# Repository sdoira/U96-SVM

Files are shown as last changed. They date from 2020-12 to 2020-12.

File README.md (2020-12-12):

# U96-SVM
Stereo vision front-end for Ultra96v2

## About
U96-SVM is an add-on board for Avnet Ultra96v2.
This board has dual CMOS image sensors and two mikroBUS sites.
This repository contains all design files for the hardware and a sample project 
which transfers stereo images through a USB interface.

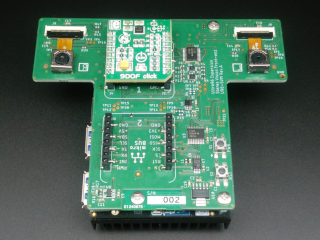
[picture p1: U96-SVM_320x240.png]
U96-SVM


## Tools

These tools are used to create this project.
1. Avnet Ultra96v2
2. Autodesk EAGLE 9.6.2
3. Xilinx Vivado 2020.1
4. Xilinx Vitis 2020.1

## PCB
This PCB is designed to be compliant with 96Boards specifications.
The number of layers is 4.
The minimum trace width and minimum drill diameter are 0.15mm and 0.25mm respectively.
This design rule is according to EuroCircuits 6D class.

EAGLE 9.6.2 is used in designing PCB.
This project doesn't contain Gerber files. EAGLE board layout file (.brd) is directly used to order manufacturing.
If you want to place an order simply upload the BRD file to the EuroCircuits website.
The assembly service is also possible by enabling the "Include assembly" option then upload the BOM file.

## USB Interface
This device is recognized as USB Video Class (UVC) device when connected to the host PC.
The sample project supports the following resolution both for USB2.0 and USB3.0.

| USB Ver. | Single Image Resolution | FPS  |
| :--- | :--- | :--- |
| 2.0 | 640 x 480 | 30 |
| 3.0 | 640 x 480 | 30 |

The left and right images are combined horizontally.
The actual output image is twice wide.

## Vivado Project
This repository contains 2 Vivado projects.
One of them is the Vivado top level project.
The other is a project for a user-created IP module.
Both of them can be created by running TCL scripts.
Refer to "create_project_dvp.pdf" and "create_project1.pdf" about how to create these projects.

## Vitis Project
The Vitis project contains a sample application named "usb_grabber".
This application, when launched, automatically starts DMA transferring of stereo images while waiting for a USB connection.
Refer to "create_vitis_project.pdf" about how to create the Vitis project.

## License
### Hardware
The hardware documentation and products included in this repository are licensed under the TAPR Open Hardware License (www.tapr.org/OHL).
The hardware documentation is contained in the following directory.

	/eagle/

### Software
The software design files included in this repository are available under the MIT license.
Such design files are contained in the following directories.

	/src/dvp/rtl/		--- Verilog-HDL RTL source
	/src/dvp/sim/		--- Verilog-HDL simulation test bench
	/src/usb_grabber/	--- C source

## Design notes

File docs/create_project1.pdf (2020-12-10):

Create project “project_1” | Dec.10.2020
1. Preface
This document describes a procedure to create “project_1” project. There are two methods to create this project. One of them is to use a script to automatically create the project. Such a script is included in the repository. The other is to create a project from scratch. This method is presented here in case the above script somehow won’t work. 2. Create “project_1” from script

Launch Vivado, type the following commands in “Tcl Console”. cd [Project Directory]/U96-SVM/vivado

source create_project_1.tcl
* board files for ultra96v2 must be installed. 3. Create “project_1” from scratch
3.1. Create a new project
If not, create the following working directory. [Project Directory]/U96-SVM/vivado

Launch Vivado, create a new project with the following properties. [Project Name]

Project name: project_1
Project location: [Project Directory]/U96-SVM/vivado
Create project subdirectory: Checked
[Project Type]
RTL Project: Selected
Do not specify sources at this time: Checked [Default Part]
Boards: Ultra96v2 Single Board Computer * board files for ultra96v2 must be installed. 3.2. Adding a block design

Click “Create Block Design” in the Flow Navigator to open “Create Block Design” dialog. Proceed with the following settings. Design name: design_1

Directory: [Project Directory]/U96-SVM/src
Specify source set: Design Sources

Click “+” icon in “BLOCK DESIGN->Diagram” to add an IP. Select “Zynq UltraScale+ MPSoC”. Click “Run Block Automation” and click “OK” with the default options.

Make the following connections. Source | Destination
pl_clk0 | maxihpm0_fpd_aclk
pl_clk0 | maxihpm1_fpd_aclk

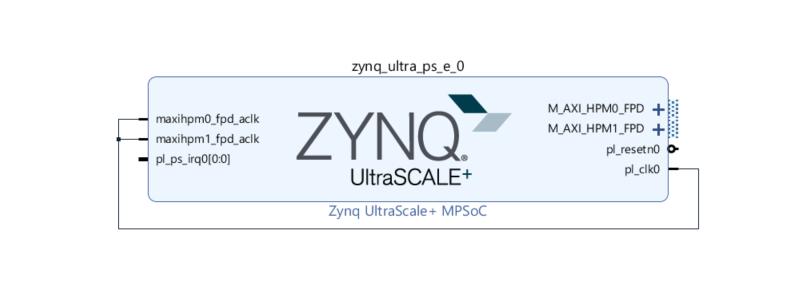
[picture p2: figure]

3.3. Adding IPs
Click “Tools->Settings...” to open “Settings” dialog. Select “Project Settings->IP->Repository”. Add the following path to “IP Repositories”. [Projecct Directory]/U96-SVM/src/ip_repo

*IP sources for “dvp” module must be exported under “ip_repo/dvp” directory.

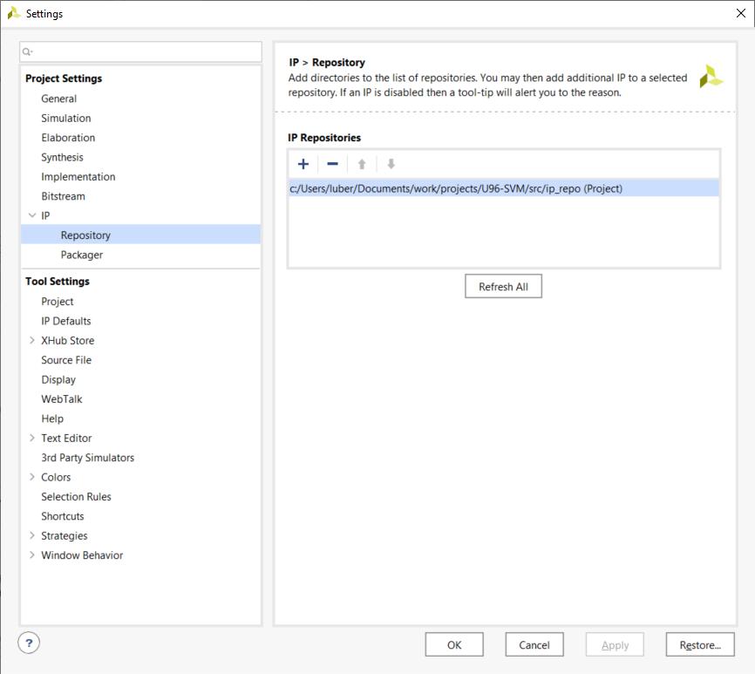
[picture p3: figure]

Double click “zynq_ultra_ps_e_0” in the BLOCK DESIGN. Select “PS-PL Configuration->PS-PL Interfaces->Slave Interfaces->AXI HP” Check “AXI HP0 FPD”. Add the following IPs by clicking “+” icon in “BLOCK DESIGN->Diagram” IP Name: “dvp_v1_0”. IP Name: MIPI CSI-2 Rx Subsystem

Component Name: mipi_csi2_rx_subsyst_0
Configuration-> Sybsystem Options-> Pixel Format: YUV422 8bit Serial Data Lanes: 2
DPHY Options->D-PHY Register Interface: Checked Shared Logic->Shared Logic->Include Shared Logic in core: Selected Pin Assigment-> Clock Lane->Pin Loc: N2
Data Lane0->Pin Loc: N5

Data Lane1->Pin Loc: M2

- IP Name: MIPI CSI-2 Rx Subsystem
Component Name: mipi_csi2_rx_subsyst_1
Configuration-> Sybsystem Options-> Pixel Format: YUV422 8bit
Serial Data Lanes: 2
DPHY Options->D-PHY Register Interface: Checked Shared Logic->Shared Logic->Include Shared Logic in example design: Selected Pin Assigment-> Clock Lane->Pin Loc: T3
Data Lane0->Pin Loc: P3
Data Lane1->Pin Loc: U2
- IP Name: Clocking Wizard
Component Name: clk_wiz_0
Output Clocks->clk_out1->Output Freq->Requested: 200
- IP Name: Clocking Wizard
Component Name: clk_wiz_1
Output Clocks->clk_out1->Output Freq->Requested: 24
Set the following port to “external” by right click the port then select “Make External”. Module | Signal
dvp_0 | gpio_in[1:0]
dvp_0 | led[1:0]
mipi_csi2_rx_subsyst_0 | mipi_phy_if
mipi_csi2_rx_subsyst_1 | mipi_phy_if
clk_wiz_1 | clk_out1
Connect the following signals. Source | Destination
Module | Signal | Module | Signal
dvp_0 | vrst1_n | mipi_csi2_rx_subsyst_0 | video_aresetn
dvp_0 | vrst2_n | mipi_csi2_rx_subsyst_1 | video_aresetn
dvp_0 | intr | zynq_ultra_ps_e_0 | pl_ps_irq0[0:0]
mipi_csi2_rx_subsyst_0 | video_out | dvp_0 | v1
mipi_csi2_rx_subsyst_1 | video_out | dvp_0 | v2
mipi_csi2_rx_subsyst_0 | clkoutphy_out | mipi_csi2_rx_subsyst_1 | clkoutphy_in
mipi_csi2_rx_subsyst_0 | pll_lock_out | mipi_csi2_rx_subsyst_1 | pll_lock_in
clk_wiz_0 | clk_out1 | mipi_csi2_rx_subsyst_0 | dphy_clk_200M
clk_wiz_0 | clk_out1 | mipi_csi2_rx_subsyst_1 | dphy_clk_200M

Click “Run Connection Automation” twice with the default parameters. Delete “reset_rtl” and “reset_rtl_0” input pins and connect to the following ports

instead. Source | Destination
Module | Signal | Module | Signal
clk_wiz_0 | reset | rst_ps8_0_100M | mb_reset
clk_wiz_1 | reset | rst_ps8_0_100M | mb_reset

Right click somewhere on the “Diagram” the click “Regenerate Layout”. “design_1” block design should look like this.

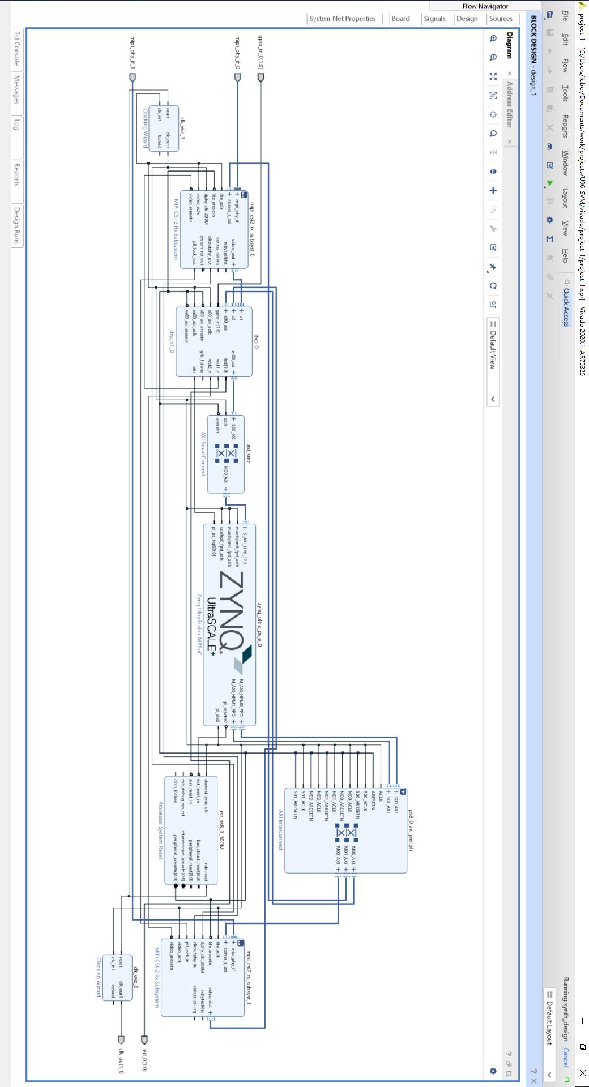
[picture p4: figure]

3.4. Create wrapper HDL
Right click “BLOCK DESIGN->Sources->Design Sources->design_1”. Click “Create HDL Wrapper...” in the menu to open “Create HDL Wrapper” dialog. Select “Let Vivado manage wrapper and auto-update” and click “OK”. 3.5. Pin assignment
Click “Run Synthesis” in the Flow Navigator. “Synthesis Completed” dialog will appear. Select “Open Synthesized Design” and click “OK”. Select “Window->I/O Ports”. “I/O Ports” tab will appear in the SYNTHESIZED DESIGN. Set the following pin location and I/O standard for each signal. Name | Package Pin | I/O Std
clk_out1_0 | E8 | LVCMOS18
gpio_in_0[1] | C5 | LVCMOS18
gpio_in_0[0] | G6 | LVCMOS18
led_0[1] | B9 | LVCMOS18
led_0[0] | A9 | LVCMOS18

Click “File->Constraints->Save As...” to open “Save Constraints” dialog. Proceed with the following settings. Create a new file: Selected

File type: XDC
File name: constr_1
File location: [Project Directory]/U96-SVM/src
3.7. Create a script
This process will make a script to automatically create this project. Click “Window->Tcl Console”. In the command line in the Tcl Console, type the following command. cd [Project Directory]/U96-SVM/vivado

write_project_tcl create_project_1.tcl

“create_project_1.tcl” will be created in the specified directory. 4. Export Hardware

Click “Generate Bitstream” in the Flow Navigator. Click “File->Export->Export Hardware” to open “Export Hardware Platform” dialog. Proceed with the following settings. [Export Hardware Platform]

Platform type: Fixed
[Output]
Include bitstream: Selected
[Files]
XSA file name: design_1_wrapper
Export to: [Project Directory]/U96-SVM/vivado

“design_1_wrapper.xsa” will be created in the specified directory.

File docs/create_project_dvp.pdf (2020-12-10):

Create project “dvp” | Dec.10.2020
1. Preface
This document describes a procedure to create “dvp” project. There are two methods to create this project. One of them is to use a script to automatically create the project. Such a script is included in the repository. The other is to create a project from scratch. This method is presented here in case the above script somehow won’t work. 2. Create “dvp” project from script

Launch Vivado, type the following commands in “Tcl Console”. cd [Project Directory]/U96-SVM/vivado

source create_project_dvp.tcl
* board files for ultra96v2 must be installed. 3. Create “dvp” project from scratch
3.1. Create a new project
Create the following working directory. [Project Directory]/U96-SVM/vivado

Launch Vivado, create a new project with the following properties. [Project Name]

Project name: dvp
Project location: [Project Directory]/U96-SVM/vivado
Create project subdirectory: Checked
[Project Type]
RTL Project: Selected
Do not specify sources at this time: Checked
[Default Part]
Boards->Display Name: Ultra96v2 Single Board Computer * board files for ultra96v2 must be installed. 3.2. Adding RTL sources

Click “Add Sources” in the Flow Navigator to open “Add Sources” dialog. Proceed with the following settings. [Add Sources]

Add or create design sources: Selected
[Add or Create Design Sources]
Click “Add Directories” to add the following directory. [Project Directory]/U96-SVM/src/dvp/rtl

Scan and add RTL include files into project: Checked Copy sources into project: Not checked

Add sources from subdirectories: Checked

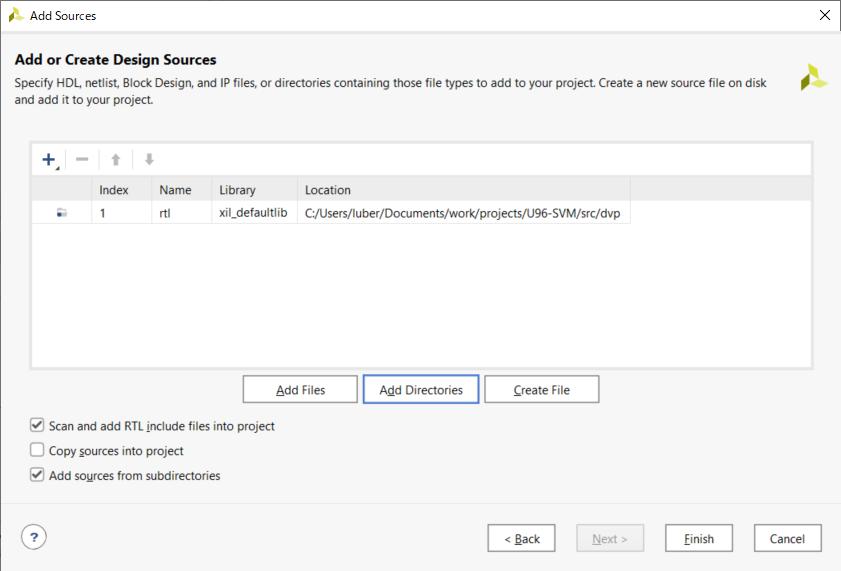
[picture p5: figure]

3.3. Adding Simulation sources
Click “Add Sources” in the Flow Navigator to open “Add Sources” dialog. Proceed with the following settings. [Add Sources]

Add or create simulation sources: Selected
[Add or Create Design Sources]
Click “Add Directories” to add the following directory. [Project Directory]/U96-SVM/src/dvp/sim

Scan and add RTL include files into project: Checked Copy sources into project: Not checked
Add sources from subdirectories: Checked
Include all design sources for simulation: Checked

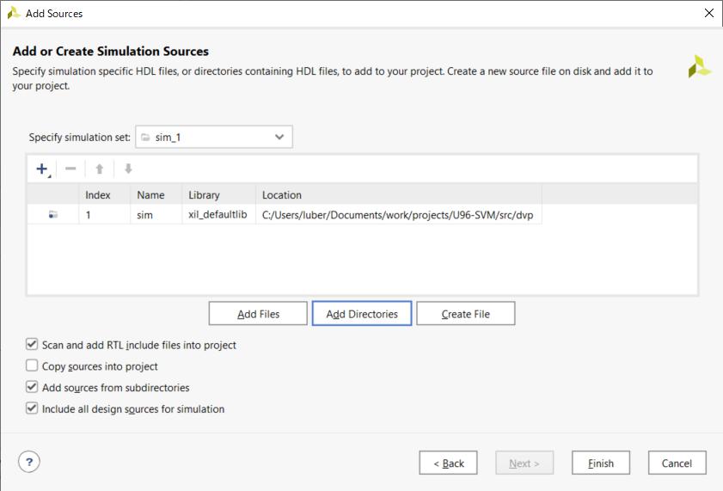
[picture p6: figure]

3.4. “arb_fifo” Click “IP Catalog” in the Flow Navigator. Select “FIFO Generator” and create an IP with the following settings. Component Name: arb_fifo

[Basic]
Fifo Implementation: Common Clock Block RAM
[Native Ports]
Data Port Parameters
Write Width: 36
Write Depth: 512
ECC, Output Register and Power Gating Options
Output Registers: Not checked
*Only the settings different from default are shown. “Generate Output Products” dialog will open. Click “Skip” for now. This is to reduce the number files that are put into git-controlled

directory in the later step.

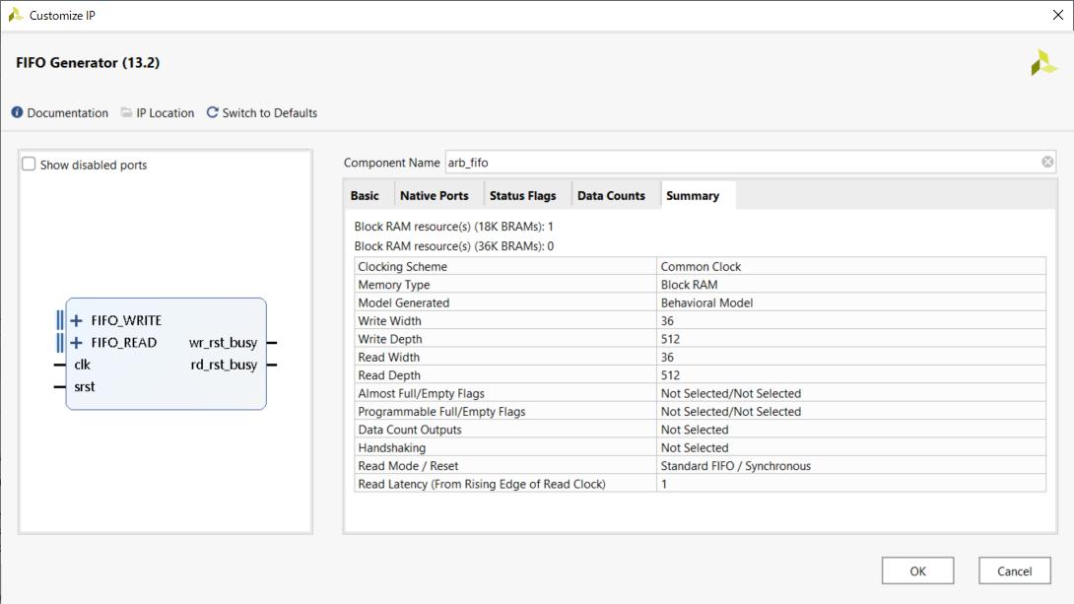
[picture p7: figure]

3.5. “grb_fifo” Click “IP Catalog” in the Flow Navigator. Select “FIFO Generator” and create an IP with the following settings. Component Name: grb_fifo

[Basic]
Fifo Implementation: Common Clock Block RAM
[Native Ports]
Data Port Parameters
Write Width: 32
Write Depth: 2048
ECC, Output Register and Power Gating Options Output Registers: Not checked
[Data Counts]
Data Count: Checked
*Only the settings different from default are shown. “Generate Output Products” dialog will open. Click “Skip” for now. This is to reduce the number files that are put into git-controlled

directory in the later step.

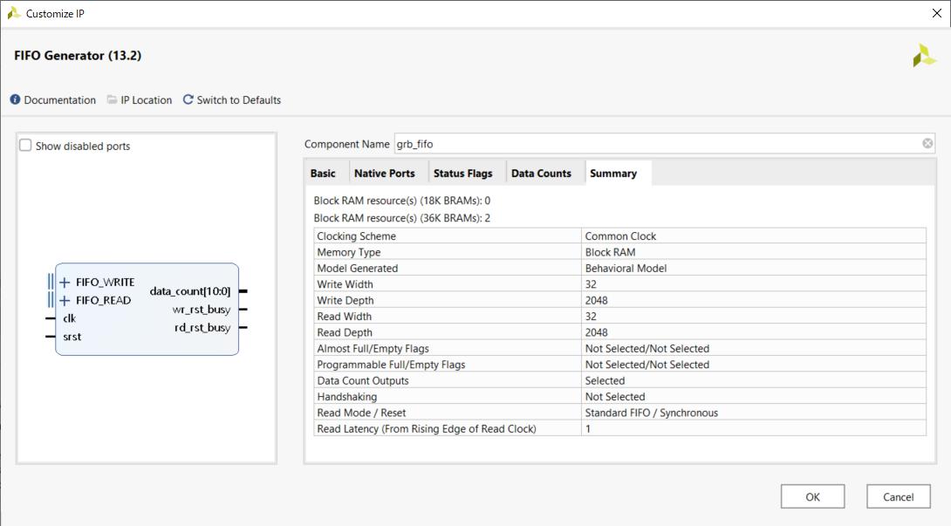
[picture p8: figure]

3.6. Moving IP sources
This process will move IP sources to git-controlled directory. Copy “arb_fifo directory as follows. Move from:

[Project Directory]/U96-SVM/vivado/dvp/dvp.srcs/sources_1/ip/arb_fifo Move to:
[Project Directory]/U96-SVM/src/dvp/ip/arb_fifo

Right click “arb_fifo” in “Sources” pane in PROJECT MANAGER. Select “Remove File from Project...”. Check “Also delete the projet local file/directory from disk”. Click OK. Click “Add Sources” in the Flow Navigator to open “Add Sources” dialog. Proceed with the following settings. [Add Sources]

Add or create design sources: Selected
[Add or Create Design Sources]
Clock “Add Files” to add the following file. [Project Directorh]/U96-SVM/src/dvp/ip/arb_fifo/arb_fifo.xci

Scan and add RTL include files into project: Checked
Copy sources into project: Not checked

Do the same operation with “grb_fifo”.

3.7. Create a script
This process will make a script that automatically creates this project. Click “Window->Tcl Console”. In the command line in the Tcl Console, type the following commands. cd [Project Directory]/U96-SVM/vivado

write_project_tcl create_project_dvp.tcl

“create_project_dvp.tcl” will be created in the specified directory. 4. Export IP

Click “Run Synthesis” in the Flow Navigator to see there aren’t any errors. Click “Tools->Create and Package New IP...” to open “Create and Package New IP” dialog. Proceed with the following settings. [Create Peripheral, Package IP or Package a Block Design]

Packaging Options
Package your current project: Selected
[Package Your Current Project]
IP location: [Project Directory]/U96-SVM/src/ip_repo/dvp

When prompted, choose to overwrite the existing files. Click “Finish”. “Package IP - dvp” will appear. Select “Review and Package”, click “Package IP”. IP sources for “dvp” are exported under “ip_repo/dvp” directory.

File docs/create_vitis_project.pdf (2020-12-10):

### Create Vitis project

Dec.10.2020
1. Preface
This document describes a procedure to create a Vitis project and a sample application named “usb_grabber”. 2. Create an application

If not, create the following Vitis working directory. [Project Directory]/U96-SVM/vitis

Launch Vitis, set the above directory as Vitis Workspace and click “Launch”. Click “Create Application Project” to open “New Application Project” dialog. Proceed with the following settings. [Platform]

Create a new platform from hardware (XSA)
Click “Browse...”
[Project Directory]/U96-SVM/vivado/design_1_wrapper.xsa [Application Project Details]
Application project name: usb_grabber
[Templates]
SW development templates: Empty Application
In “Application Project Settings”, click “Navigate to BSP Settings”. Click “Modify BSP Settings...” in “Board Support Package”. “Board Support Package Settings” dialog will open. Click “Overview->standalone” and make the following modification. Name | Value
stdin | psu_uart_1
stdout | psu_uart_1
This change is necessary because uart_1 is used as stdin/out in Ultra96v2 board.

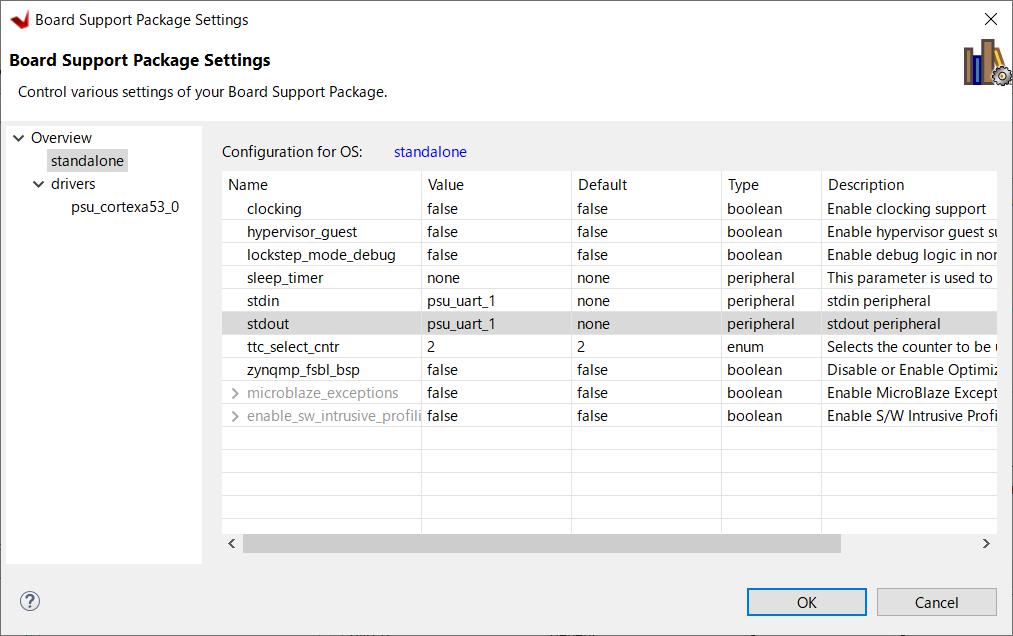
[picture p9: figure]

3. Import sources
Right click “usb_grabber_system->usb_grabber->src” in the “Explorer” and click “Import Sources...” from the menu to open “Import Sources” dialog. Proceed with the following settings. From directory: [Project Directory]/U96-SVM/src/usb_grabber

Click “Select All”. Click “Advanced”. Create links in workspace: Checked. (This will create symbolic links under the project directory without actual copying.)

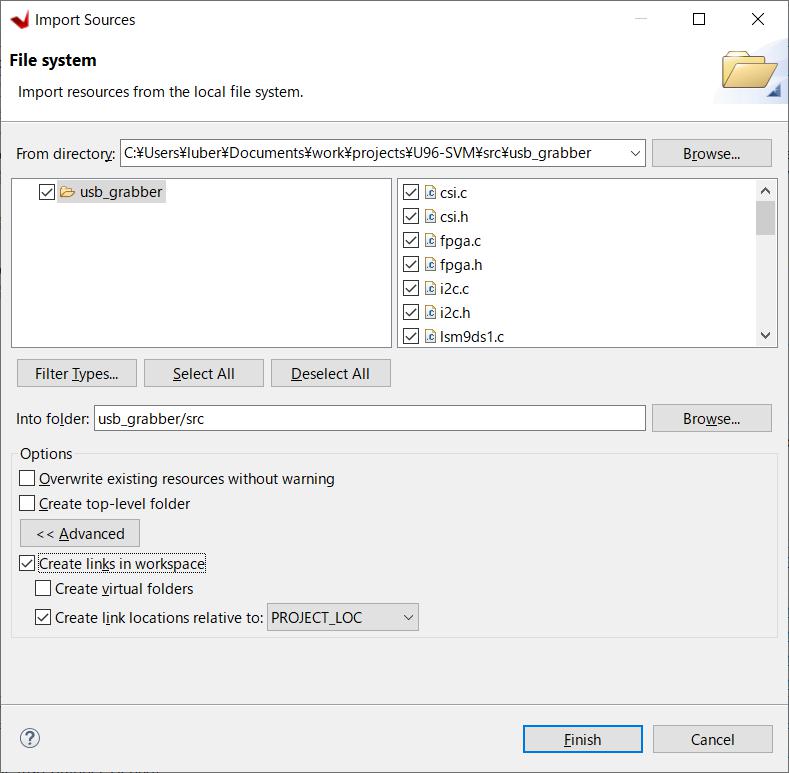
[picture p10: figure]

Click “Project->Build Project” to build the project.

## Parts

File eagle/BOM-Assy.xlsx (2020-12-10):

BOM for post-assembly
Qty. | Part | Device | Manufacturer | MPN | Supplier | SPN | Website | Note
2 | OV5640 image sensor | OV5640 automatically zoom camera module | - | - | Xiongfa | - | https://www.alibaba.com/product-detail/OV5640-automatically-zoom-camera-module_60431391972.html | -
 |  | OV5640 automatically zoom camera module 5-megapixe | - | - | New electronics | - | https://www.alibaba.com/product-detail/New-electronics-OV5640-automatically-zoom-camera_60445311854.html | Pin assignment on their website is not correct
4 | Standoff | HEX STANDOFF M2.5X0.45 STEEL 7MM | Wurth | 971070151 | Digi-Key | 732-10386-ND | - | -
4 | Screw | M2.5 x 6mm | - | - | - | - | - | -
Copyright (C) 2020 Nu-Gate Technology. All rights reserved.
Licensed under the TAPR Open Hardware License (www.tapr.org/OHL)

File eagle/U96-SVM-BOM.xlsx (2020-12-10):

Qty | Value | Device | Parts | Description | Manufacturer | MPN | Supplier | SPN
6 | 1u | C-EUC0402 | C1, C2, C14, C15, C16, C17 | CAP CER 1UF 10V X5R 0603 | Murata | GRM188R61A105KA61J | Digi-Key | 490-6408-1-ND
2 | 10n | C-EUC0402 | C10, C19 | CAP CER 10000PF 50V C0G/NP0 0603 | Murata | GRM1885C1H103JA01D | Digi-Key | 490-9666-1-ND
11 | 100n | C-EUC0402 | C3, C4, C5, C6, C7, C8, C9, C11, C12, C13, C18 | CAP CER 0.1UF 10V X5R 0402 | Murata | GRM155R61A104KA01J | Digi-Key | 490-6297-1-ND
6 |  | FIDUCIAL | FID1, FID2, FID3, FID4, FID5, FID6 | Fiducial marks, 1mm | - | - | - | -
1 | 96B-LS-57202 | 96B-LS-57202 | J2 | CONN HEADER SMD 40POS 2MM | Amphenol | 57202-G52-20LF | Digi-Key | 609-2632-ND
2 | MIKROE_BUS_CONN_LNPTC081KFXC | MIKROE_BUS_CONN_LNPTC081KFXC | J3, J4 | CONN HDR 8POS 0.1 TIN SMD | Sullins | NPTC081KFXC-RC | Digi-Key | S5600-ND
2 | MIKROE_BUS_CONN_RNPTC081KFXC | MIKROE_BUS_CONN_RNPTC081KFXC | J5, J6 | CONN HDR 8POS 0.1 TIN SMD | Sullins | NPTC081KFXC-RC | Digi-Key | S5600-ND
1 | 96B-HS-5177986-2 | 96B-HS-5177986-2 | J7 | CONN PLUG 60POS SMD GOLD | TE | 2-5177986-2 | Digi-Key | A99209CT-ND
2 | 5051102491 | 5051102491 | J8, J9 | CONN FFC/FPC BOTTOM 24P .5MM R/A | Molex | 5051102491 | Digi-Key | WM11289CT-ND
2 |  | BLM15AX | L1, L2 | FERRITE BEAD 220 OHM 0603 1LN | Murata | BLM18AG221SN1D | Digi-Key | 490-1012-1-ND
12 | 4.7k | R-EU_R0402 | R1, R2, R3, R4, R10, R11, R12, R13, R44, R45, R46, R47 | RES SMD 4.7K OHM 5% 1/16W 0402 | Yageo | RC0402JR-074K7L | Digi-Key | 311-4.7KJRCT-ND
1 | 8.2k/0.1% | R-EU_R0402 | R16 | RES SMD 8.2K OHM 0.1% 1/16W 0402 | Yageo | RT0402BRD078K2L | Digi-Key | YAG4318CT-ND
1 | 6.2k/0.1% | R-EU_R0402 | R17 | RES SMD 6.2K OHM 0.1% 1/16W 0402 | Yageo | RT0402BRD076K2L | Digi-Key | YAG4302CT-ND
3 | 0 | R-EU_R0402 | R24, R38, R39 | RES SMD 0 OHM JUMPER 1/16W 0402 | Yageo | RC0402JR-070RL | Digi-Key | 311-0.0JRCT-ND
5 | NM | R-EU_R0402 | R5, R6, R14, R15, R25 | No Mount | - | - | - | -
3 | 200k | R-EU_R0402 | R7, R8, R9 | RES SMD 200K OHM 5% 1/16W 0402 | Yageo | RC0402JR-07200KL | Digi-Key | 311-200KJRCT-ND
2 | 430181038816 | 430181038816 | S1, S2 | SWITCH TACTILE SPST-NO 0.05A 12V | Wurth | 430181038816 | Digi-Key | 732-7003-1-ND
20 | TPB1,27 | TPB1,27 | TP1, TP2, TP3, TP4, TP5, TP6, TP7, TP8, TP9, TP10, TP11, TP12, TP13, TP14, TP15, TP16, TP17, TP18, TP19, TP20 | Test pad | - | - | - | -
1 | TPS79533DCQ | TPS79533DCQ | U10 | IC REG LIN 3.3V 500MA SOT223-6 | TI | TPS79533DCQR | Digi-Key | 296-13810-1-ND
2 | TXS0108EPWR | TXS0108EPWR | U2, U3 | IC TRNSLTR BIDIRECTIONAL 20TSSOP | TI | TXS0108EPWR | Digi-Key | 296-23011-1-ND
2 | PCA9306DCU | PCA9306DCU | U4, U5 | IC TRNSLTR BIDIRECTIONAL 8VSSOP | TI | PCA9306DCUR | Digi-Key | 296-17988-1-ND
1 | LSF0102DCTR | LSF0102DCTR | U6 | IC TRNSLTR BIDIRECTIONAL SM8 | TI | LSF0102DCTR | Digi-Key | 296-40398-1-ND
1 | MCP3202-ST | MCP3202-ST | U7 | IC ADC 12BIT SAR 8TSSOP | Microchip | MCP3202T-CI/ST | Digi-Key | MCP3202T-CI/STCT-ND
1 | TPS73201DBV | TPS73201DBV | U8 | IC REG LIN POS ADJ 250MA SOT23-5 | TI | TPS73201DBVR | Digi-Key | 296-32554-1-ND
1 | 5PB1102PGG | 5PB1102PGG | U9 | IC CLOCK BUFFER 1:2 8TSSOP | Renesas | 5PB1102PGGI | Digi-Key | 800-2889-5-ND
1 | 24MHz | KC2520Z | Y1 | XTAL OSC XO 24.0000MHZ CMOS SMD | Kyocera | KC2520Z24.0000C1KX00 | Digi-Key | 1253-2019-1-ND
 | Copyright (C) 2020 Nu-Gate Technology. All rights reserved.
 | Licensed under the TAPR Open Hardware License (www.tapr.org/OHL)

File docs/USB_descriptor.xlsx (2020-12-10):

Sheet: USB2.x
Descriptor | Offset | Field | Size | Value | Description
Device | 0 | bLength | 1 | 12h | 18 bytes
 | 1 | bDescriptorType | 1 | 01h | DEVICE
 | 2 | bcdUSB | 2 | 0210h | USB specification revision 2.10
 | 4 | bDeviceClass | 1 | EFh | Miscellaneous Device Class
 | 5 | bDeviceSubClass | 1 | 02h | Common Class
 | 6 | bDeviceProtocol | 1 | 01h | Interface Association Descriptor
 | 7 | bMaxPacketSize0 | 1 | 40h | Control endpoint packet size is 64 bytes
 | 8 | idVendor | 2 | C80Ah | Vendor ID
 | 10 | idProduct | 2 | 1034h | Product ID
 | 12 | bcdDevice | 2 | 0001h | Device release code
 | 14 | iManufacturer | 1 | 01h | String ID
 | 15 | iProduct | 1 | 02h | String ID
 | 16 | iSerialNumber | 1 | 00h | String ID
 | 17 | bNumConfiguration | 1 | 01h | This device has one configuration
Configuration | 0 | bLength | 1 | 09h | 9 bytes
 | 1 | bDescriptorType | 1 | 02h | CONFIGURATION
 | 2 | wTotalLength | 2 | 00B1h | 177 bytes
 | 4 | bNumInterfaces | 1 | 02h | This device has two interfaces
 | 5 | bConfigurationValue | 1 | 01h | ID of this configuration
 | 6 | iConfiguration | 1 | 00h | Unused
 | 7 | bmAttributes | 1 | C0h | Self-powered, No remote-wakeup
 | 8 | bMaxPower | 1 | 00h | Always self-powered
Interface Association | 0 | bLength | 1 | 08h | 8 bytes
 | 1 | bDescriptorType | 1 | 0Bh | INTERFACE ASSOCIATION
 | 2 | bFirstInterface | 1 | 00h | Interface number of the VideoControl interface that is associated with this function.
 | 3 | bInterfaceCount | 1 | 02h | Number of contiguous Video interfaces that are associated with this function.
 | 4 | bFunctionClass | 1 | 0Eh | CC_VIDEO
 | 5 | bFunctionSubClass | 1 | 03h | SC_VIDEO_INTERFACE_COLLECTION
 | 6 | bFunctionProtocol | 1 | 00h | Not used. Must be set to PC_PROTOCOL_UNDEFINED.
 | 7 | iFunction | 1 | 02h | Index to string descriptor that contains the string <Your Product Name> in Unicode. Have to match iInterface field in Standard VC Interface Descriptor.
Standard Interface #0 (VideoControl) | 0 | bLength | 1 | 09h | 9 bytes
 | 1 | bDescriptorType | 1 | 04h | INTERFACE
 | 2 | bInterfaceNumber | 1 | 00h | Index of this interface
 | 3 | bAlternateSetting | 1 | 00h | Index of this setting
 | 4 | bNumEndpoints | 1 | 01h | 1 endpoint (interrupt endpoint)
 | 5 | bInterfaceClass | 1 | 0Eh | CC_VIDEO
 | 6 | bInterfaceSubClass | 1 | 01h | SC_VIDEOCONTROL
 | 7 | bInterfaceProtocol | 1 | 00h | PC_PROTOCOL_UNDEFINED
 | 8 | iInterface | 1 | 02h | Index to string descriptor that contains the string <Your Product Name> in Unicode. Have to match iFunction field of the Standard Video Interface Collection IAD.
Class-specific Control Interface | 0 | bLength | 1 | 0Dh | 13 bytes
 | 1 | bDescriptorType | 1 | 24h | CS_INTERFACE
 | 2 | bDescriptorSubType | 1 | 01h | VC_HEADER subtype
 | 3 | bcdUVC | 2 | 0100h | Revision of class specification that this device is based upon. For this example, the device complies with Video Class specification version 1.5
 | 4 | wTotalLength | 2 | 0034h | Total size of class-specific descriptors
 | 5 | dwClockFrequency | 4 | 05F5_E100h | Use of this field has been deprecated. The device clock frequency is 100 MHz.
 | 6 | bInCollection | 1 | 01h | Number of streaming interfaces
 | 7 | baInterfaceNr(1) | 1 | 01h | VideoStreaming interface 1 belongs to this VideoControl interface.
Input Terminal #1 (Camera) | 0 | bLength | 1 | 12h | 18 bytes
 | 1 | bDescriptorType | 1 | 24h | CS_INTERFACE
 | 2 | bDescriptorSubType | 1 | 02h | VC_INPUT_TERMINAL
 | 3 | bTerminalID | 1 | 01h | ID of this input terminal
 | 4 | wTerminalType | 2 | 0201h | ITT_CAMERA type. This terminal is a camera terminal representing the CMOS sensor.
 | 6 | bAssocTerminal | 1 | 00h | No association
 | 7 | iTerminal | 1 | 00h | Unused
 | 8 | wObjectiveFocalLengthMin | 2 | 0000h | No optical zoom supported
 | 10 | wObjectiveFocalLengthMax | 2 | 0000h | No optical zoom supported
 | 12 | wOcularFocalLength | 2 | 0000h | No optical zoom supported
 | 14 | bControlSize | 1 | 03h | The size of the bmControls is 3 bytes
 | 15 | bmControls | 3 | 00000000h | doesn't support any control
Processing Unit #2 | 0 | bLength | 1 | 0Ch | 12 bytes
 | 1 | bDescriptorType | 1 | 24h | CS_INTERFACE
 | 2 | bDescriptorSubType | 1 | 05h | VC_PROCESSING_UNIT
 | 3 | bUnitID | 1 | 02h | ID of this unit
 | 4 | bSourceID | 1 | 01h | This input pin of this unit is connected to the output pin of unit with 1.
 | 5 | wMaxMultiplier | 2 | 4000h | Unused
 | 7 | bControlSize | 1 | 03h | Size of the bmControls field, in bytes.
 | 8 | bmControls | 3 | 00_0000h | doesn't support any control
 | 12 | iProcessing | 1 | 00h | Unused
Output Terminal #3 | 0 | bLength | 1 | 09h | 9 bytes
 | 1 | bDescriptorType | 1 | 24h | CS_INTERFACE
 | 2 | bDescriptorSubType | 1 | 03h | VC_OUTPUT_TERMINAL
 | 3 | bTerminalID | 1 | 03h | ID of this terminal
 | 4 | wTerminalType | 2 | 0101h | TT_STREAMING type. This terminal is a USB streaming terminal.
 | 6 | bAssocTerminal | 1 | 00h | No association
 | 7 | bSourceID | 1 | 02h | The input pin of this unit is connected to the output pin of unit 2.
 | 8 | iTerminal | 1 | 00h | Unused
Standard Interrupt Endpoint #1 (VideoControl) | 0 | bLength | 1 | 07h | 7 bytes
 | 1 | bDescriptorType | 1 | 05h | ENDPOINT
 | 2 | bEndpointAddress | 1 | 82h | IN endpoint 2
 | 3 | bmAttributes | 1 | 03h | Interrupt transfer type
 | 4 | wMaxPacketSize | 2 | 0040h | 64-byte status packet
 | 6 | bInterval | 1 | 05h | Poll at least every 5 ms
Class-specific Interrupt Endpoint | 0 | bLength | 1 | 05h | 5 bytes
 | 1 | bDescriptorType | 1 | 25h | CS_ENDPOINT
 | 2 | bDescriptorSubType | 1 | 03h | EP_INTERRUPT
 | 3 | wMaxTransferSize | 2 | 0040h | 64-bytes status packet
Standard Interface #1 (VideoStreaming) Alt#0 (Operational) | 0 | bLength | 1 | 09h | 9 bytes
 | 1 | bDescriptorType | 1 | 04h | INTERFACE
 | 2 | bInterfaceNumber | 1 | 01h | Index of this interface
 | 3 | bAlternateSetting | 1 | 00h | Index of this alternate setting
 | 4 | bNumEndpoints | 1 | 01h | 1 endpoint
 | 5 | bInterfaceClass | 1 | 0Eh | CC_VIDEO
 | 6 | bInterfaceSubClass | 1 | 02h | SC_VIDEOSTREAMING
 | 7 | bInterfaceProtocol | 1 | 00h | PC_PROTOCOL_UNDEFINED
 | 8 | iInterface | 1 | 00h | Unused
Class-specific Input Header | 0 | bLength | 1 | 0Eh | 14 bytes
 | 1 | bDescriptorType | 1 | 24h | CS_INTERFACE
 | 2 | bDescriptorSubType | 1 | 01h | VS_INPUT_HEADER
 | 3 | bNumFormats | 1 | 01h | One format descriptor follows.
 | 4 | wTotalLength | 2 | 0047h | Total size of class-specific VideoStreaming interface descriptors
 | 6 | bEndpointAddress | 1 | 83h | Address of the isochronous endpoint used for video data
 | 7 | bmInfo | 1 | 00h | No dynamic format change supported.
 | 8 | bTerminalLink | 1 | 03h | This VideoStreaming interface supplies terminal ID 3 (Output Terminal).
 | 9 | bStillCaptureMethod | 1 | 00h | Device supports still image capture method 2.
 | 10 | bTriggerSupport | 1 | 00h | Hardware trigger not supported for still image capture
 | 11 | bTriggerUsage | 1 | 00h | General purpose button event not applicable
 | 12 | bControlSize | 1 | 01h | Size of the bmaControls field.
 | 13 | bmaControls | 1 | 00h | No VideoStreaming specific controls are supported.
Payload-Specific Video Format #1 (Uncompressed YUY2) | 0 | bLength | 1 | 1Bh | 27 bytes
 | 1 | bDescriptorType | 1 | 24h | CS_INTERFACE
 | 2 | bDescriptorSubType | 1 | 04h | VS_FORMAT_UNCOMPRESSED
 | 3 | bFormatIndex | 1 | 01h | Index of this format descriptor
 | 4 | bNumFrameDescriptors | 1 | 01h | One frame descriptor for this format follows
 | 5 | guidFormat | 16 | 32595559_ 00100000_ AA000080_ 719B3800h | GUID for YUY2
 | 21 | bBitsPerPixel | 1 | 10h | 16 bits per pixel
 | 22 | bDefaultFrameIndex | 1 | 01h | Default frame index is 1.
 | 23 | bAspectRatioX | 1 | 00h | The X dimension of the picture aspect ratio. ->Non-interlaced stream – not required.
 | 24 | bAspectRatioY | 1 | 00h | The X dimension of the picture aspect ratio. ->Non-interlaced stream – not required.
 | 25 | bmInterlaceFlags | 1 | 00h | Non-interlaced stream
 | 26 | bCopyProtect | 1 | 00h | No restrictions
Payload-Specific Frame #1 (1280x480 30fps) | 0 | bLength | 1 | 1Eh | 30 bytes
 | 1 | bDescriptorType | 1 | 24h | CS_INTERFACE
 | 2 | bDescriptorSubType | 1 | 05h | VS_FRAME_UNCOMPRESSED
 | 3 | bFormatIndex | 1 | 01h | First (and only) frame descriptor
 | 4 | bmCapabilities | 1 | 00h | Still images using capture method 1 are supported at this frame setting. D1: Fixed frame-rate.
 | 5 | wWidth | 1 | 0500h | Width of frame is 1280 pixels.
 | 7 | wHeight | 2 | 01E0h | Height of frame is 480 pixels.
 | 9 | dwMinBitRate | 2 | 1194_0000h | Min 294,912,999 bits/s, 30fps
 | 13 | dwMaxBitRate | 4 | 1194_0000h | Max 294,912,999 bits/s, 30fps
 | 17 | dwMaxVideoFrameBufSize | 4 | 0012_C000h | Max frame size 1,228,800 bytes.
 | 21 | dwDefaultFrameInterval | 4 | 0005_1615h | Default frame interval is 333,333ns (30fps).
 | 25 | bFrameIntervalType | 1 | 01h | Descrete frame interval
 | 26 | dwFrameInterval | 4 | 0005_1615h | Frame interval is 333,333ns (30fps).
Standard Endpoint #2 Bulk/Input (VideoStreaming) | 0 | bLength | 1 | 07h | 7 bytes
 | 1 | bDescriptorType | 1 | 05h | ENDPOINT
 | 2 | bEndpointAddress | 1 | 83h | IN endpoint 3
 | 3 | bmAttributes | 1 | 02h | Bulk-Transfer
 | 4 | wMaxPacketSize | 2 | 0200h | Max packet size of 512 bytes
 | 6 | bInterval | 1 | 01h | One frame interval

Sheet: USB3.x
Descriptor | Offset | Field | Size | Value | Description
Device | 0 | bLength | 1 | 12h | 18 bytes
 | 1 | bDescriptorType | 1 | 01h | DEVICE
 | 2 | bcdUSB | 2 | 0300h | USB specification revision 3.00
 | 4 | bDeviceClass | 1 | EFh | Miscellaneous Device Class
 | 5 | bDeviceSubClass | 1 | 02h | Common Class
 | 6 | bDeviceProtocol | 1 | 01h | Interface Association Descriptor
 | 7 | bMaxPacketSize0 | 1 | 09h | Control endpoint packet size is 2^9=512 bytes
 | 8 | idVendor | 2 | C80Bh | Vendor ID
 | 10 | idProduct | 2 | 1035h | Product ID
 | 12 | bcdDevice | 2 | 0002h | Device release code
 | 14 | iManufacturer | 1 | 01h | String ID
 | 15 | iProduct | 1 | 02h | String ID
 | 16 | iSerialNumber | 1 | 00h | String ID
 | 17 | bNumConfiguration | 1 | 01h | This device has one configuration
Configuration | 0 | bLength | 1 | 09h | 9 bytes
 | 1 | bDescriptorType | 1 | 02h | CONFIGURATION
 | 2 | wTotalLength | 2 | 00BEh | 190 bytes
 | 4 | bNumInterfaces | 1 | 02h | This device has two interfaces
 | 5 | bConfigurationValue | 1 | 01h | ID of this configuration
 | 6 | iConfiguration | 1 | 00h | Unused
 | 7 | bmAttributes | 1 | C0h | Self-powered, No remote-wakeup
 | 8 | bMaxPower | 1 | 00h | Always self-powered
Interface Association | 0 | bLength | 1 | 08h | 8 bytes
 | 1 | bDescriptorType | 1 | 0Bh | INTERFACE ASSOCIATION
 | 2 | bFirstInterface | 1 | 00h | Interface number of the VideoControl interface that is associated with this function.
 | 3 | bInterfaceCount | 1 | 02h | Number of contiguous Video interfaces that are associated with this function.
 | 4 | bFunctionClass | 1 | 0Eh | CC_VIDEO
 | 5 | bFunctionSubClass | 1 | 03h | SC_VIDEO_INTERFACE_COLLECTION
 | 6 | bFunctionProtocol | 1 | 00h | Not used. Must be set to PC_PROTOCOL_UNDEFINED.
 | 7 | iFunction | 1 | 02h | Index to string descriptor that contains the string <Your Product Name> in Unicode. Have to match iInterface field in Standard VC Interface Descriptor.
Standard Interface #0 (VideoControl) | 0 | bLength | 1 | 09h | 9 bytes
 | 1 | bDescriptorType | 1 | 04h | INTERFACE
 | 2 | bInterfaceNumber | 1 | 00h | Index of this interface
 | 3 | bAlternateSetting | 1 | 00h | Index of this setting
 | 4 | bNumEndpoints | 1 | 01h | 1 endpoint (interrupt endpoint)
 | 5 | bInterfaceClass | 1 | 0Eh | CC_VIDEO
 | 6 | bInterfaceSubClass | 1 | 01h | SC_VIDEOCONTROL
 | 7 | bInterfaceProtocol | 1 | 00h | PC_PROTOCOL_UNDEFINED
 | 8 | iInterface | 1 | 02h | Index to string descriptor that contains the string <Your Product Name> in Unicode. Have to match iFunction field of the Standard Video Interface Collection IAD.
Class-specific Control Interface | 0 | bLength | 1 | 0Dh | 13 bytes
 | 1 | bDescriptorType | 1 | 24h | CS_INTERFACE
 | 2 | bDescriptorSubType | 1 | 01h | VC_HEADER subtype
 | 3 | bcdUVC | 2 | 0100h | Revision of class specification that this device is based upon. For this example, the device complies with Video Class specification version 1.5
 | 4 | wTotalLength | 2 | 0035h | Total size of class-specific descriptors
 | 5 | dwClockFrequency | 4 | 05F5_E100h | Use of this field has been deprecated. The device clock frequency is 100MHz.
 | 6 | bInCollection | 1 | 01h | Number of streaming interfaces
 | 7 | baInterfaceNr(1) | 1 | 01h | VideoStreaming interface 1 belongs to this VideoControl interface.
Input Terminal #1 (Camera) | 0 | bLength | 1 | 12h | 18 bytes
 | 1 | bDescriptorType | 1 | 24h | CS_INTERFACE
 | 2 | bDescriptorSubType | 1 | 02h | VC_INPUT_TERMINAL
 | 3 | bTerminalID | 1 | 01h | ID of this input terminal
 | 4 | wTerminalType | 2 | 0201h | ITT_CAMERA type. This terminal is a camera terminal representing the CMOS sensor.
 | 6 | bAssocTerminal | 1 | 00h | No association
 | 7 | iTerminal | 1 | 00h | Unused
 | 8 | wObjectiveFocalLengthMin | 2 | 0000h | No optical zoom supported
 | 10 | wObjectiveFocalLengthMax | 2 | 0000h | No optical zoom supported
 | 12 | wOcularFocalLength | 2 | 0000h | No optical zoom supported
 | 14 | bControlSize | 1 | 03h | The size of the bmControls is 3 bytes
 | 15 | bmControls | 3 | 00000000h | doesn't support any control
Processing Unit #2 | 0 | bLength | 1 | 0Ch | 12 bytes
 | 1 | bDescriptorType | 1 | 24h | CS_INTERFACE
 | 2 | bDescriptorSubType | 1 | 05h | VC_PROCESSING_UNIT
 | 3 | bUnitID | 1 | 02h | ID of this unit
 | 4 | bSourceID | 1 | 01h | This input pin of this unit is connected to the output pin of unit with 1.
 | 5 | wMaxMultiplier | 2 | 4000h | Unused
 | 7 | bControlSize | 1 | 03h | Size of the bmControls field, in bytes.
 | 8 | bmControls | 3 | 00_0000h | doesn't support any control
 | 12 | iProcessing | 1 | 00h | Unused
Output Terminal #3 | 0 | bLength | 1 | 09h | 9 bytes
 | 1 | bDescriptorType | 1 | 24h | CS_INTERFACE
 | 2 | bDescriptorSubType | 1 | 03h | VC_OUTPUT_TERMINAL
 | 3 | bTerminalID | 1 | 03h | ID of this terminal
 | 4 | wTerminalType | 2 | 0101h | TT_STREAMING type. This terminal is a USB streaming terminal.
 | 6 | bAssocTerminal | 1 | 00h | No association
 | 7 | bSourceID | 1 | 02h | The input pin of this unit is connected to the output pin of unit 2.
 | 8 | iTerminal | 1 | 00h | Unused
Standard Interrupt Endpoint #1 (VideoControl) | 0 | bLength | 1 | 07h | 7 bytes
 | 1 | bDescriptorType | 1 | 05h | ENDPOINT
 | 2 | bEndpointAddress | 1 | 82h | IN endpoint 2
 | 3 | bmAttributes | 1 | 03h | Interrupt transfer type
 | 4 | wMaxPacketSize | 2 | 0040h | 64-byte status packet
 | 6 | bInterval | 1 | 01h | Poll at least every 1 ms
SuperSpeed Endpoint Companion | 0 | bLength | 1 | 06h
 | 1 | bDescriptorType | 1 | 30h | SUPERSPEED_USB_ENDPOINT_COMPANION
 | 2 | bMaxBurst | 1 | 00h
 | 3 | bmAttributes | 1 | 00h
 | 4 | wBytesPerInterval | 2 | 0040h
Class-specific Interrupt Endpoint | 0 | bLength | 1 | 05h | 5 bytes
 | 1 | bDescriptorType | 1 | 25h | CS_ENDPOINT
 | 2 | bDescriptorSubType | 1 | 03h | EP_INTERRUPT
 | 3 | wMaxTransferSize | 2 | 0040h | 64-bytes status packet
Standard Interface #1 (VideoStreaming) Alt#0 (Operational) | 0 | bLength | 1 | 09h | 9 bytes
 | 1 | bDescriptorType | 1 | 04h | INTERFACE
 | 2 | bInterfaceNumber | 1 | 01h | Index of this interface
 | 3 | bAlternateSetting | 1 | 00h | Index of this alternate setting
 | 4 | bNumEndpoints | 1 | 01h | 1 endpoint
 | 5 | bInterfaceClass | 1 | 0Eh | CC_VIDEO
 | 6 | bInterfaceSubClass | 1 | 02h | SC_VIDEOSTREAMING
 | 7 | bInterfaceProtocol | 1 | 00h | PC_PROTOCOL_UNDEFINED
 | 8 | iInterface | 1 | 00h | Unused
Class-specific Input Header | 0 | bLength | 1 | 0Eh | 14 bytes
 | 1 | bDescriptorType | 1 | 24h | CS_INTERFACE
 | 2 | bDescriptorSubType | 1 | 01h | VS_INPUT_HEADER
 | 3 | bNumFormats | 1 | 01h | One format descriptor follows.
 | 4 | wTotalLength | 2 | 0047h | Total size of class-specific VideoStreaming interface descriptors
 | 6 | bEndpointAddress | 1 | 83h | Address of the isochronous endpoint used for video data
 | 7 | bmInfo | 1 | 00h | No dynamic format change supported.
 | 8 | bTerminalLink | 1 | 03h | This VideoStreaming interface supplies terminal ID 3 (Output Terminal).
 | 9 | bStillCaptureMethod | 1 | 00h | Device supports still image capture method 2.
 | 10 | bTriggerSupport | 1 | 00h | Hardware trigger not supported for still image capture
 | 11 | bTriggerUsage | 1 | 00h | General purpose button event not applicable
 | 12 | bControlSize | 1 | 01h | Size of the bmaControls field.
 | 13 | bmaControls | 1 | 00h | No VideoStreaming specific controls are supported.
Payload-Specific Video Format #1 (Uncompressed YUY2) | 0 | bLength | 1 | 1Bh | 27 bytes
 | 1 | bDescriptorType | 1 | 24h | CS_INTERFACE
 | 2 | bDescriptorSubType | 1 | 04h | VS_FORMAT_UNCOMPRESSED
 | 3 | bFormatIndex | 1 | 01h | Index of this format descriptor
 | 4 | bNumFrameDescriptors | 1 | 01h | One frame descriptor for this format follows
 | 5 | guidFormat | 16 | 32595559_ 00100000_ AA000080_ 719B3800h | GUID for YUY2
 | 21 | bBitsPerPixel | 1 | 10h | 16 bits per pixel
 | 22 | bDefaultFrameIndex | 1 | 01h | Default frame index is 1.
 | 23 | bAspectRatioX | 1 | 00h | The X dimension of the picture aspect ratio. ->Non-interlaced stream – not required.
 | 24 | bAspectRatioY | 1 | 00h | The X dimension of the picture aspect ratio. ->Non-interlaced stream – not required.
 | 25 | bmInterlaceFlags | 1 | 00h | Non-interlaced stream
 | 26 | bCopyProtect | 1 | 00h | No restrictions
Payload-Specific Frame #1 (Uncompressed YUY2) | 0 | bLength | 1 | 1Eh | 30 bytes
 | 1 | bDescriptorType | 1 | 24h | CS_INTERFACE
 | 2 | bDescriptorSubType | 1 | 05h | VS_FRAME_UNCOMPRESSED
 | 3 | bFormatIndex | 1 | 01h | First (and only) frame descriptor
 | 4 | bmCapabilities | 1 | 00h | Still images using capture method 1 are supported at this frame setting. D1: Fixed frame-rate.
 | 5 | wWidth | 1 | 0500h | Width of frame is 1280 pixels.
 | 7 | wHeight | 2 | 01E0h | Height of frame is 480 pixels.
 | 9 | dwMinBitRate | 2 | 1194_0000h | Min 294,912,999 bits/s, 30fps
 | 13 | dwMaxBitRate | 4 | 1194_0000h | Max 294,912,999 bits/s, 30fps
 | 17 | dwMaxVideoFrameBufSize | 4 | 0012_C000h | Max frame size 1,228,800 bytes.
 | 21 | dwDefaultFrameInterval | 4 | 0005_1615h | Default frame interval is 333,333ns (30fps).
 | 25 | bFrameIntervalType | 1 | 01h | Descrete frame interval
 | 26 | dwFrameInterval | 4 | 0005_1615h | Frame interval is 333,333ns (30fps).
Standard Endpoint #2 Bulk/Input (VideoStreaming) | 0 | bLength | 1 | 07h | 7 bytes
 | 1 | bDescriptorType | 1 | 05h | ENDPOINT
 | 2 | bEndpointAddress | 1 | 83h | IN endpoint 3
 | 3 | bmAttributes | 1 | 02h | Bulk-Transfer
 | 4 | wMaxPacketSize | 2 | 0400h | Max packet size of 1024 bytes
 | 6 | bInterval | 1 | 00h | Not used
SuperSpeed Endpoint Companion | 0 | bLength | 1 | 06h
 | 1 | bDescriptorType | 1 | 30h | SUPERSPEED_USB_ENDPOINT_COMPANION
 | 2 | bMaxBurst | 1 | 0Fh | 16 packet / burst
 | 3 | bmAttributes | 1 | 00h
 | 4 | wBytesPerInterval | 2 | 0000h

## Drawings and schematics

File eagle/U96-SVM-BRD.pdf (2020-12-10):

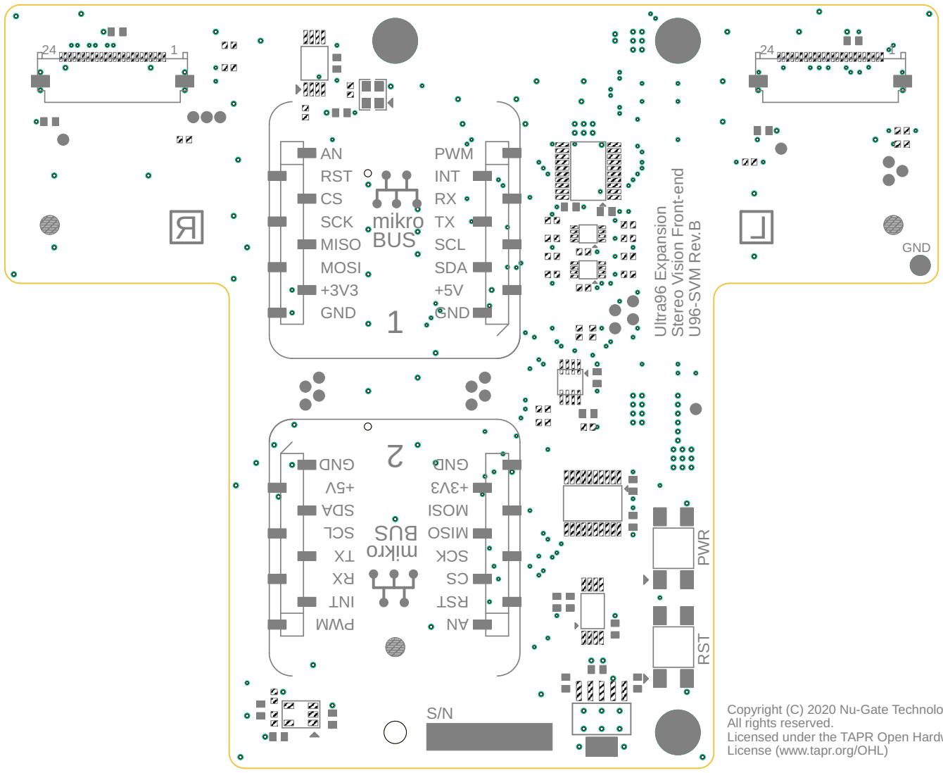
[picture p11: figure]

R L 12 GND Ultra96 Expansion Stereo Vision Front-end U96-SVM Rev.B PWR RST S/N NA TSRSC KCS OSI M I SOM 3V3+ DNG ANRST CSSCK MISO MOSI +3V3 GND GND +5V SDA SCL TXRXINT PWM DNG V5+ ADS L CSXTXR TNI MWP 24 1 24 1 mikro BUS or ki m SUB Copyright (C) 2020 Nu-Gate Technology. All rights reserved. Licensed under the TAPR Open Hardware License (www.tapr.org/OHL)

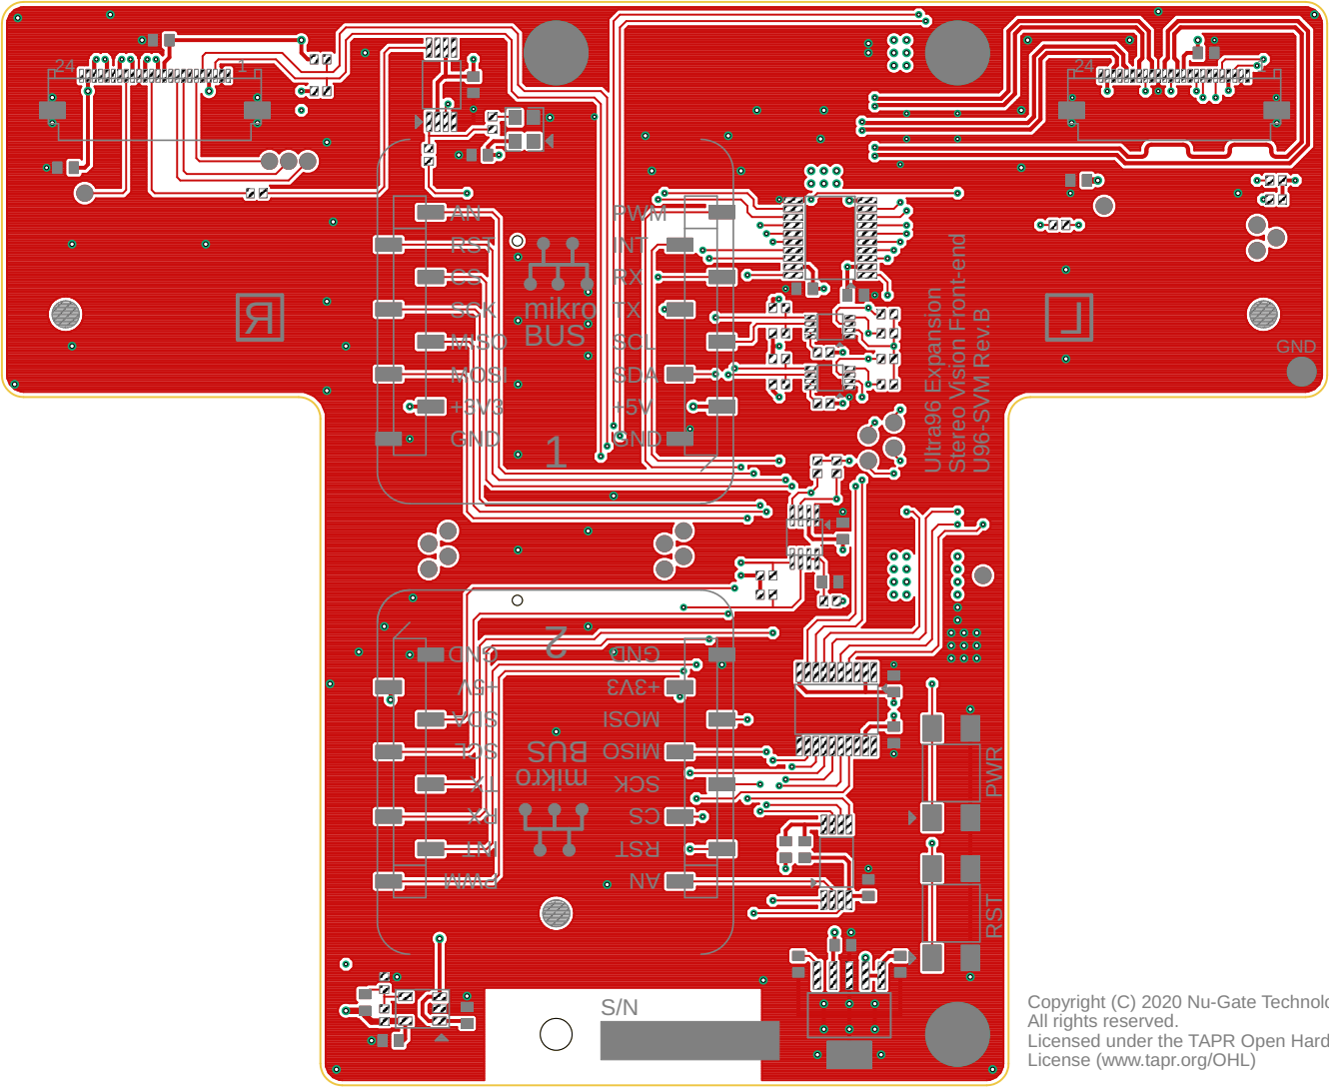
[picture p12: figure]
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

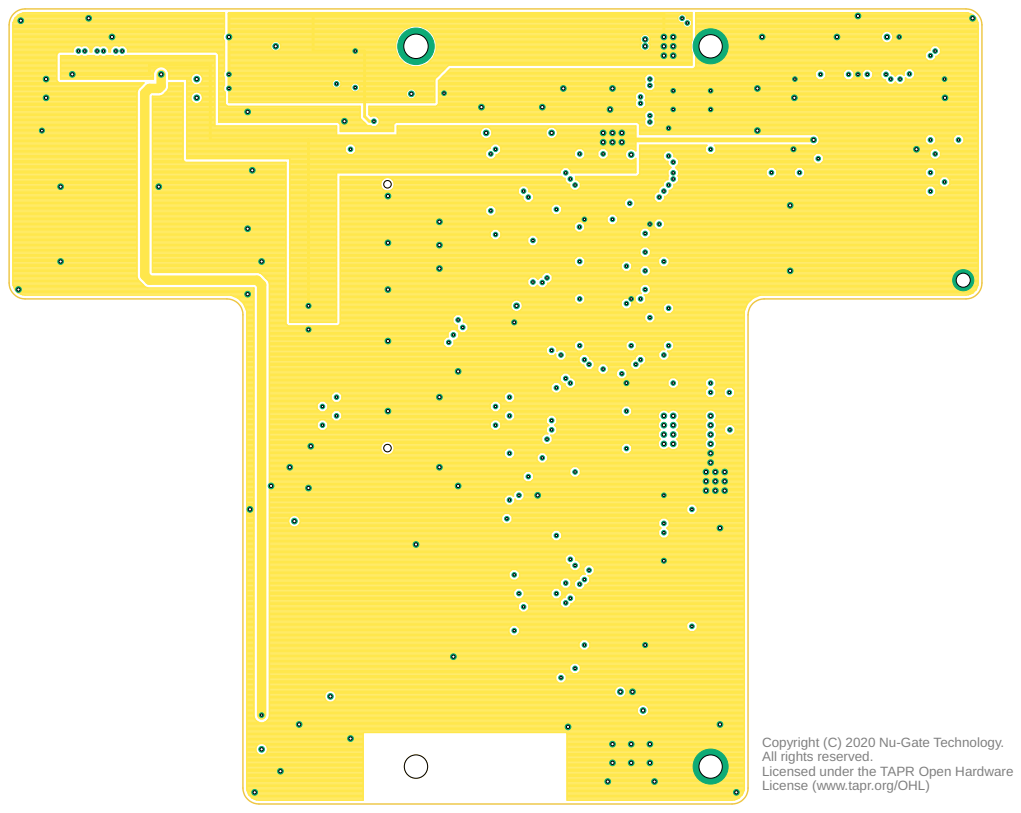
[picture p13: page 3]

Copyright (C) 2020 Nu-Gate Technology. All rights reserved. Licensed under the TAPR Open Hardware

License (www.tapr.org/OHL)

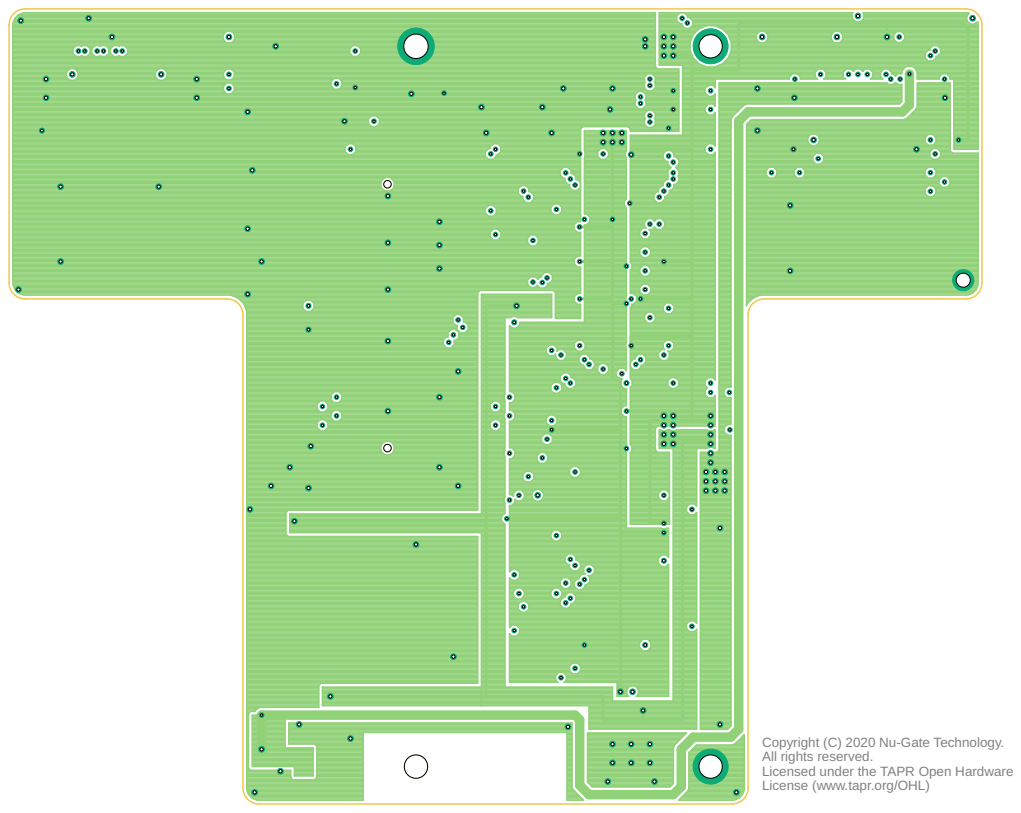
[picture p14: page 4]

Copyright (C) 2020 Nu-Gate Technology. All rights reserved. Licensed under the TAPR Open Hardware

License (www.tapr.org/OHL)

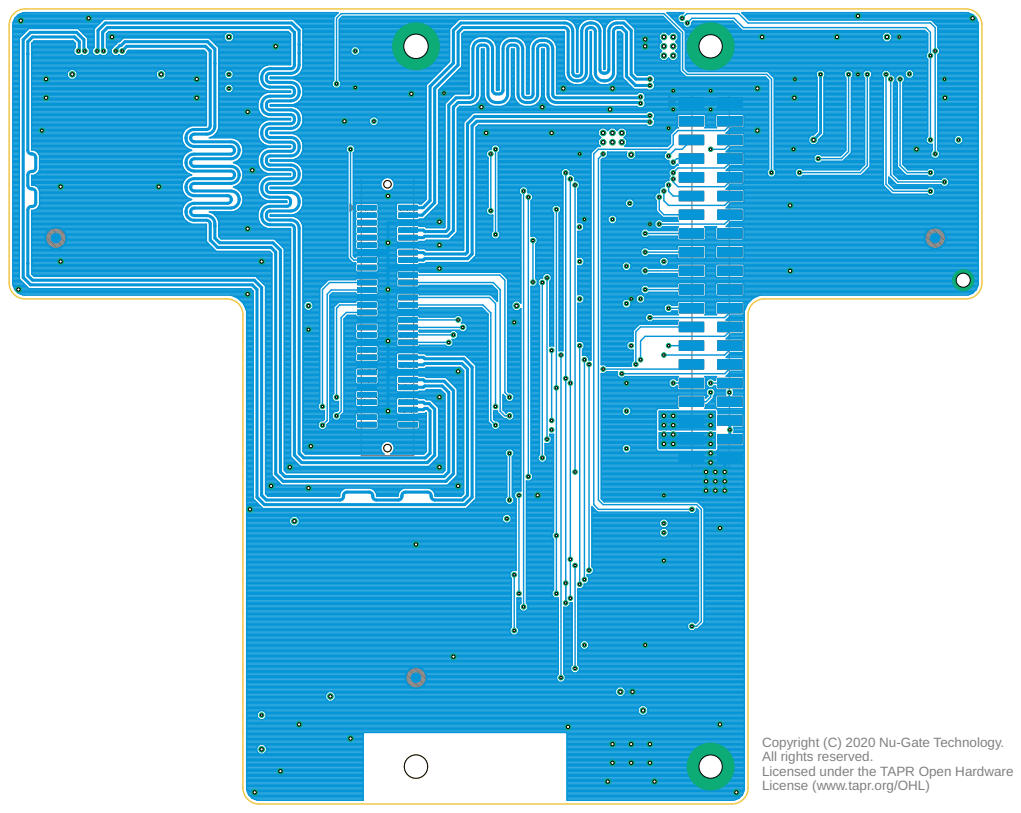
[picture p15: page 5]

Copyright (C) 2020 Nu-Gate Technology. All rights reserved. Licensed under the TAPR Open Hardware

License (www.tapr.org/OHL)

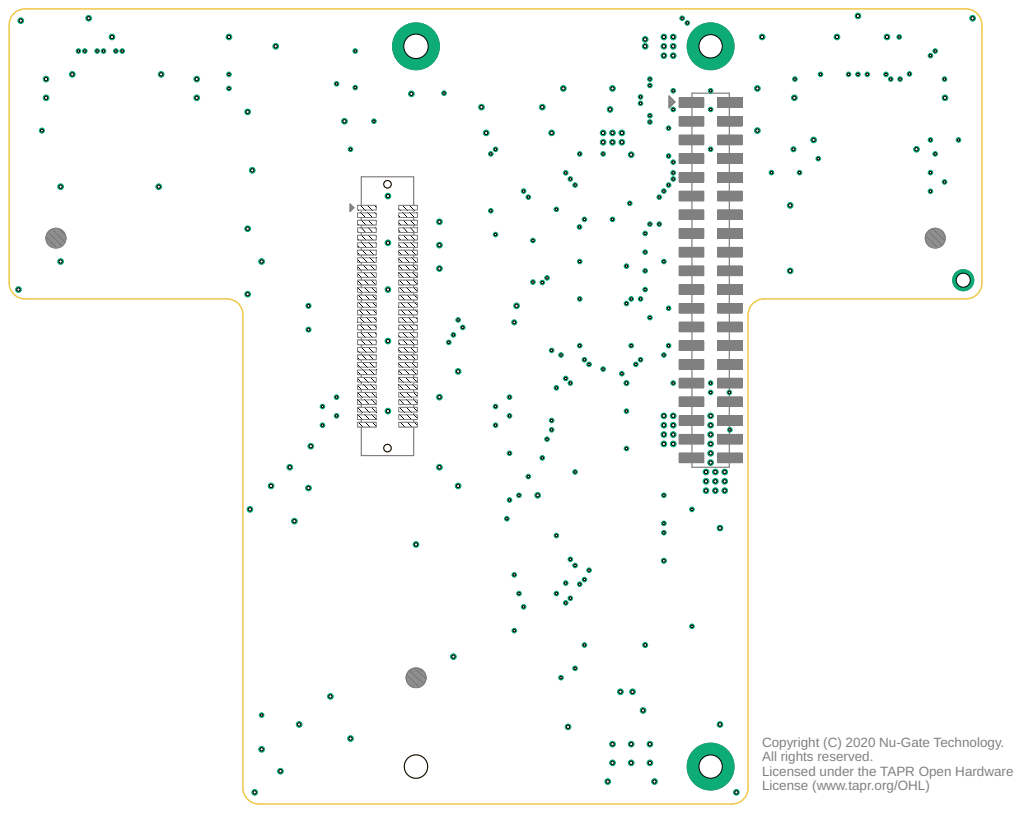
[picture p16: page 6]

Copyright (C) 2020 Nu-Gate Technology. All rights reserved. Licensed under the TAPR Open Hardware

License (www.tapr.org/OHL)

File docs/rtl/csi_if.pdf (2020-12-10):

### Nov.24.2020

### Block diagram

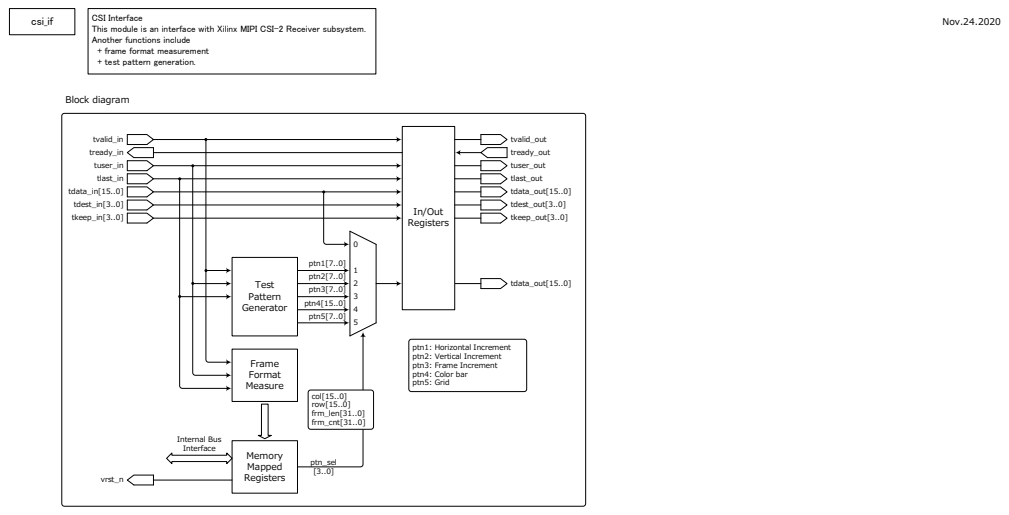
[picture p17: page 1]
csi_if; CSI Interface; Memory Mapped Registers; tdata_out[15..0]; Frame Format Measure; Test Pattern Generator; tvalid_in tready_in tuser_in tlast_in tdata_in[15..0] tdest_in[3..0]; tkeep_in[3..0]; In/Out Registers; tvalid_out; tuser_out tlast_out tdata_out[15..0] tdest_out[3..0] tkeep_out[3..0]; tready_out; Internal Bus Interface; ptn1[7..0] ptn2[7..0] ptn3[7..0] ptn4[15..0] ptn5[7..0]; vrst_n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

This module is an interface with Xilinx MIPI CSI-2 Receiver subsystem.
Another functions include
+ frame format measurement
+ test pattern generation.

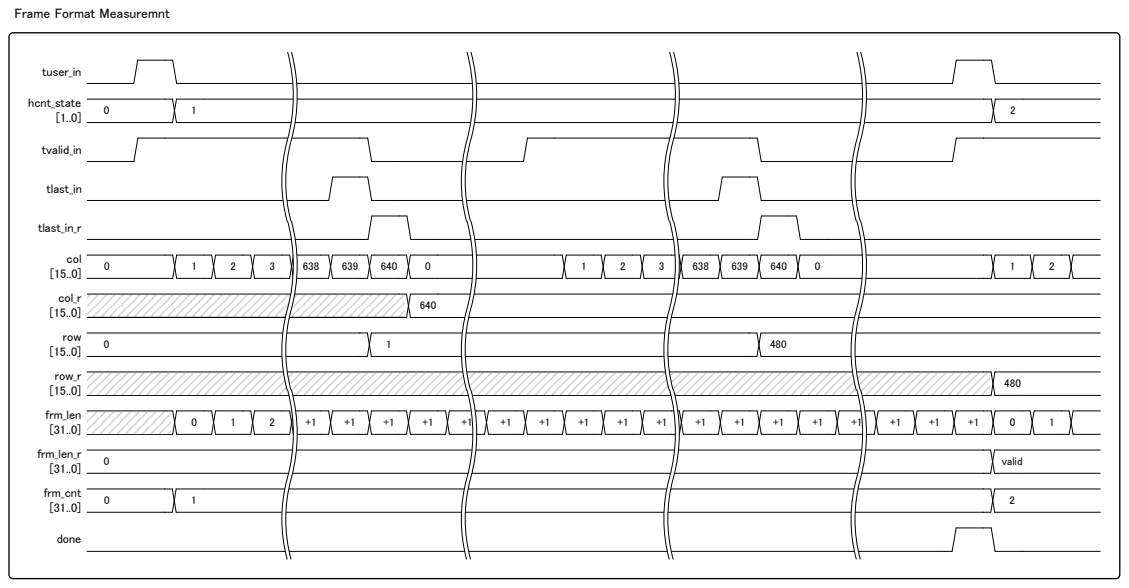
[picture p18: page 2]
tvalid_in; col [15..0]; tlast_in; tuser_in; hcnt_state [1..0]; row; frm_len; frm_len_r; valid; frm_cnt; done; col_r; tlast_in_r; row_r

Frame Format Measuremnt

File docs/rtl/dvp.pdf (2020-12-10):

### Nov.26.2020

### Block diagram

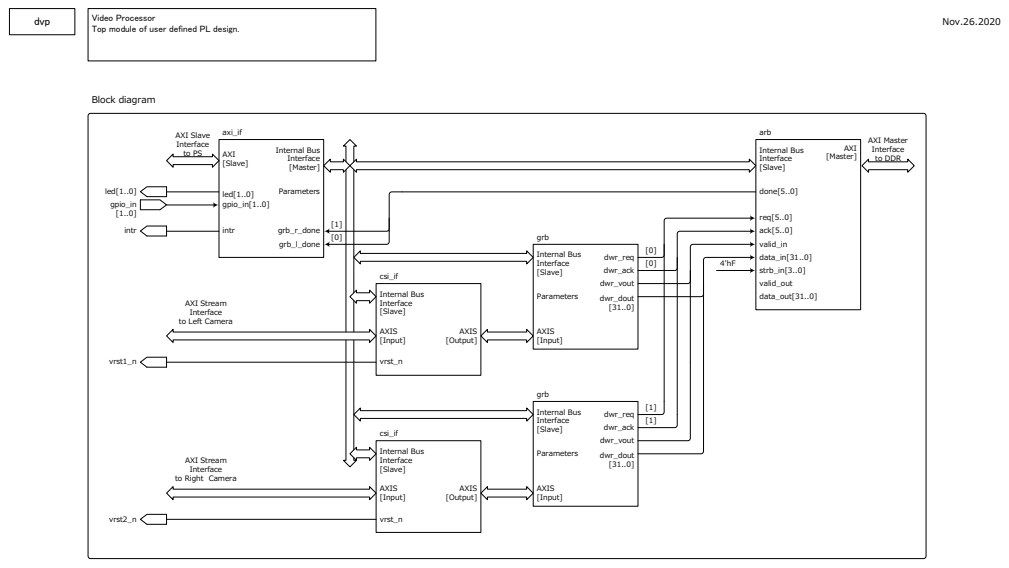
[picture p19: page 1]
dvp; Video Processor; AXI [Slave]; axi_if; Internal Bus Interface [Master]; led[1..0] gpio_in[1..0]; Parameters; grb_r_done grb_l_done; intr; AXIS [Input]; grb; dwr_req; dwr_ack; dwr_dout [31..0]; dwr_vout; Internal Bus Interface [Slave]; csi_if; AXIS [Output]; vrst_n; AXI Slave Interface to PS; arb; AXI [Master]; req[5..0]; done[5..0]; ack[5..0]; valid_in data_in[31..0] strb_in[3..0] valid_out data_out[31..0]; AXI Master Interface to DDR; vrst1_n; vrst2_n; led[1..0] gpio_in [1..0]

Top module of user defined PL design.

AXI Stream
Interface
to Left Camera

to Right Camera

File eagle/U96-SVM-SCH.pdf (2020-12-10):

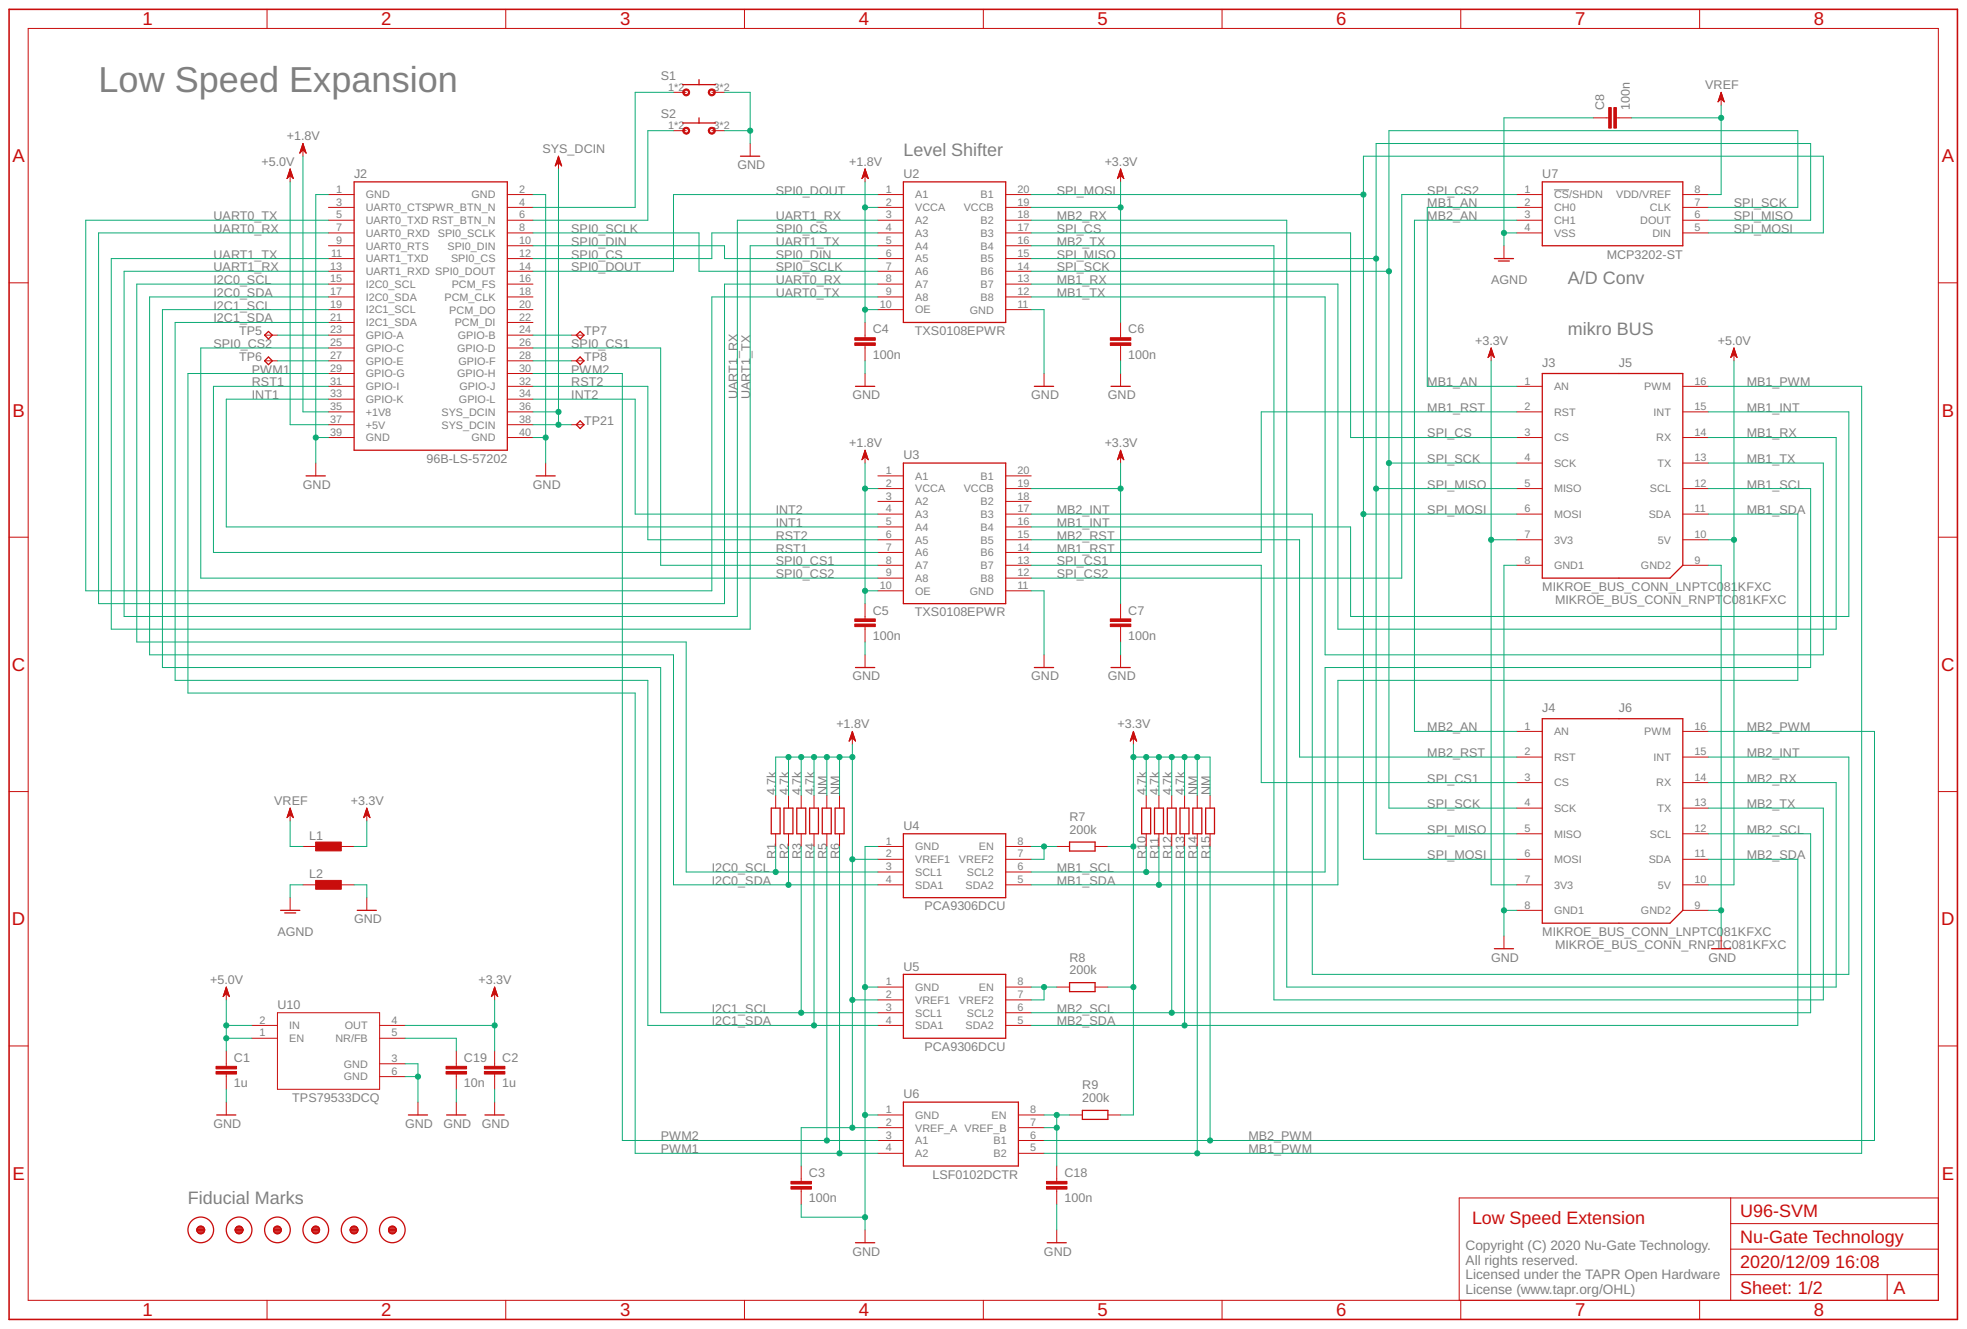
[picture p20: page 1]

SPI_CS1 | | 14 | MB2_RX
SPI_SCK | | 13 RX | MB2_TX

Copyright (C) 2020 Nu-Gate Technology. All rights reserved. Licensed under the TAPR Open Hardware

License (www.tapr.org/OHL)

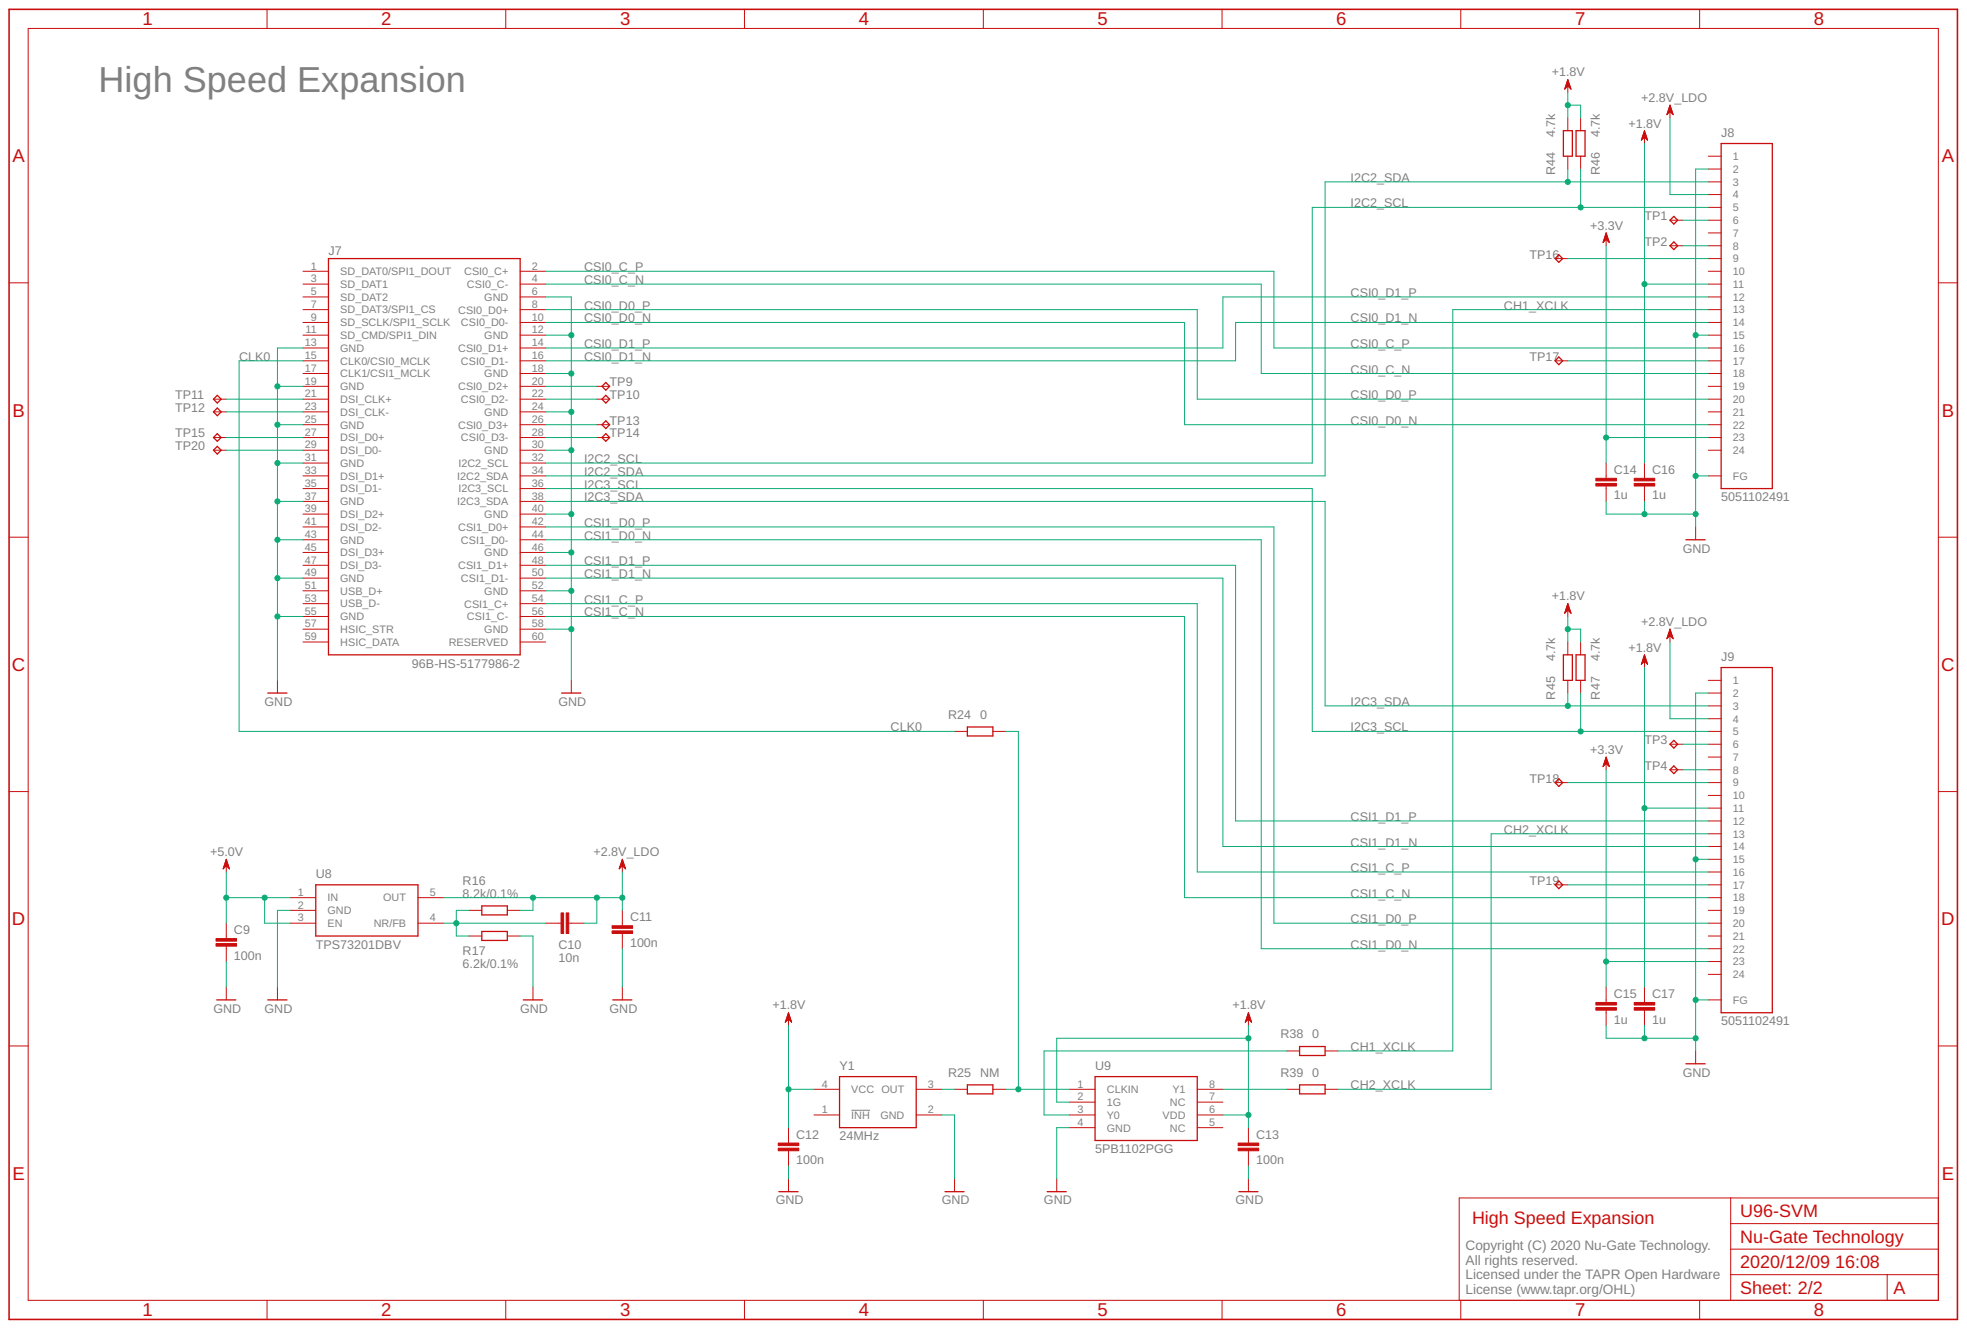
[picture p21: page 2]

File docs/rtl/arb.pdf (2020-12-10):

arb | DDR Arbiter This module arbitrates various write/read requests to/from DDR.

# Nov.23.2020

# Block diagram

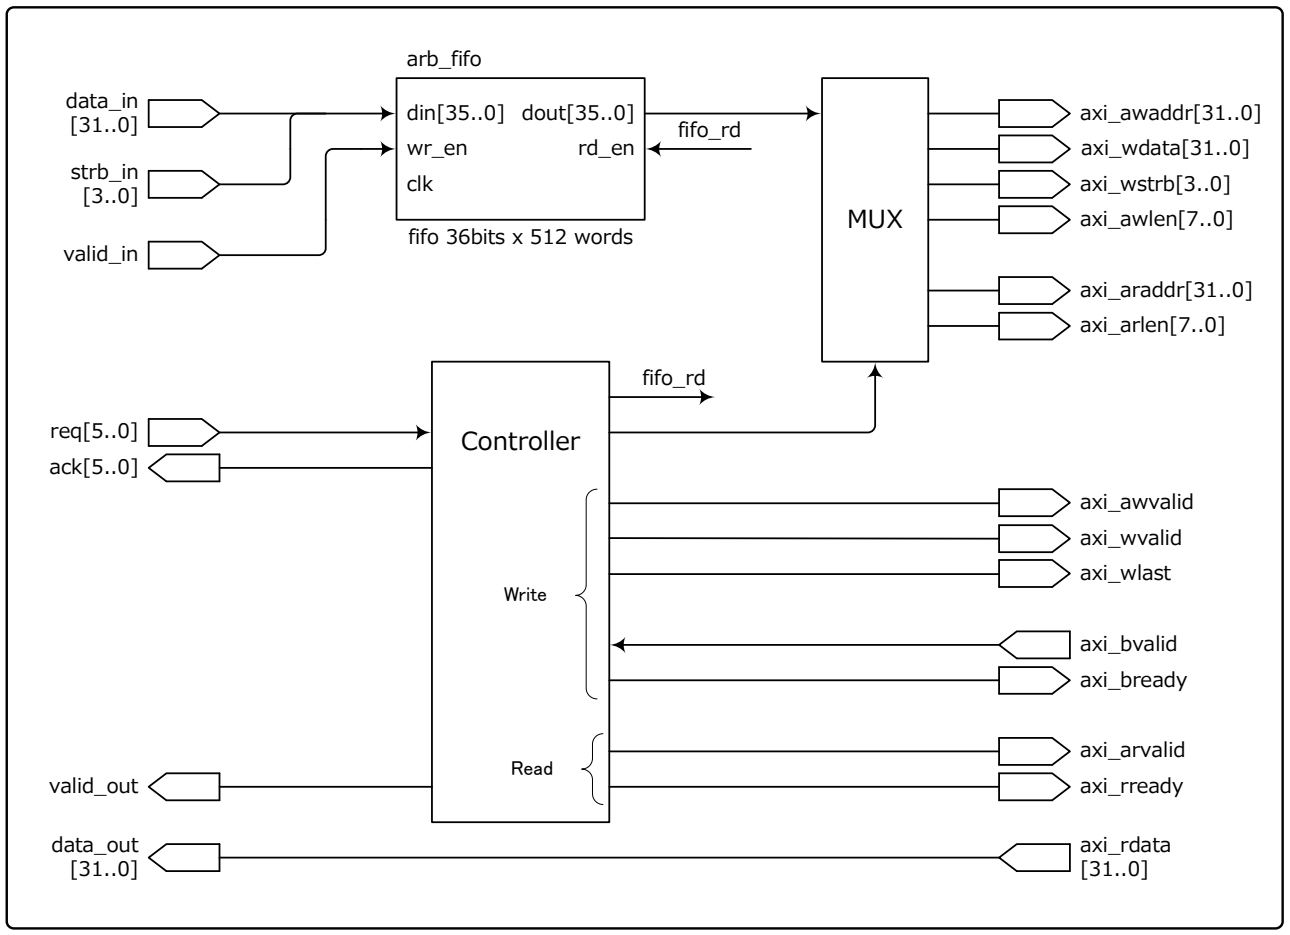
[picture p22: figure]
din[35..0]; dout[35..0]; arb_fifo; fifo 36bits x 512 words; clk; fifo_rd; Controller; valid_in; valid_out; data_in [31..0]; strb_in [3..0]; data_out [31..0]; req[5..0] ack[5..0]; MUX; axi_awvalid; axi_bvalid axi_bready; axi_rdata [31..0]; axi_wvalid axi_wlast; axi_arvalid axi_rready; axi_awaddr[31..0]; axi_wstrb[3..0]; axi_wdata[31..0]; axi_awlen[7..0]; axi_araddr[31..0] axi_arlen[7..0]; Write; Read

// AXI I/F
input | | axi_aclk;
output | [31:0] | axi_awaddr;
output | [7:0] | axi_awlen;
output | | axi_awvalid;
input | | axi_awready;
output | [31:0] | axi_wdata;
output | | axi_wlast;
output | | axi_wvalid;
input | | axi_wready;
input | | axi_bvalid;
output | | axi_bready;

### DDR Write (where burst length is 4)

rd_state 0 -> 1: ~empty & awready & wready & arready 1 -> 2: ~rd_wrn 1 -> 5: rd_wrn 2 -> 3: unconditional 3 -> 4: wlast & wready 4 -> 0: bready 5 -> 0: rlast; CMD [31..10]: reserved; 9]: last; 8]: rd_wrn; [ 7.. 0]: bst_len_m1; req; ack; valid_in; fifo_din; cmd; addr; data; fifo_wr; fifo_empty; rd_state; fifo_rd; bst_cnt; bst_end; last_bit; rd_wrn; valid; done; axi_awvalid; axi_awaddr; axi_wvalid; axi_wdata; axi_wlast; axi_bvalid; axi_bready; fifo_dout; data [1]; data [2]; data [3]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

command bits are
decoded at this timing

### DDR Read (where burst length is 4)

req; ack; valid_in; fifo_din; cmd; addr; fifo_wr; fifo_empty; rd_state; fifo_rd; bst_cnt; bst_end; last_bit; rd_wrn; valid; done; axi_arvalid; axi_araddr; axi_rvalid; axi_rdata; fifo_dout; (bst_cnt == bst_len_m1); transition 1->5 when (rd_wrn == 1); asserted when (last_bit == 1)

command bits are
decoded at this timing

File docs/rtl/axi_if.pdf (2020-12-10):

axi_if | AXI Interface This module bridges AXI interface and internal interface. The internal interface is a simple SRAM-like interface.

### Nov.24.2020

### Block diagram

Memory Mapped Registers; Write Process; axi_awvalid axi_awaddr[13..0]; axi_awready; axi_wvalid axi_wdata[31..0]; axi_wready; axi_bready; axi_bresp[1..0]; axi_bvalid; Read Process; axi_arvalid axi_araddr[13..0]; axi_arready; axi_rvalid axi_rdata[31..0]; axi_rready; Bus Converter; addr[11..0] cs[3..0] wr wrdata[31..0] rddata[31..0]; led[1..0] gpio_in[1..0] hgt[10..0] wdt[10..0]

0000 – 0FFF | cs[0]
1000 – 1FFF | cs[1]
2000 – 2FFF | cs[2]
3000 – 3FFF | cs[3]

Memory Space Mapping

axi_arvalid; axi_araddr [13..0]; addr [11..0]; valid; rddata [31..0]; [Internal Bus]; [AXI Bus]; axi_arready; axi_rvalid; axi_rready; axi_rddata; 4 clock cycles; axi_awvalid; axi_awaddr [13..0]; axi_wvalid; axi_wdata; wrdata; axi_awready; axi_wready; axi_bvalid; axi_bresp [1..0]; axi_bready; OKAY

AXI Register Write

AXI Register Read

‘axi_rvalid’ will be asserted after 4 clock
cycles after valid addres. Read data must be
prepared within this time period.

Write operation will take
place when both valid and
ready signals are high.

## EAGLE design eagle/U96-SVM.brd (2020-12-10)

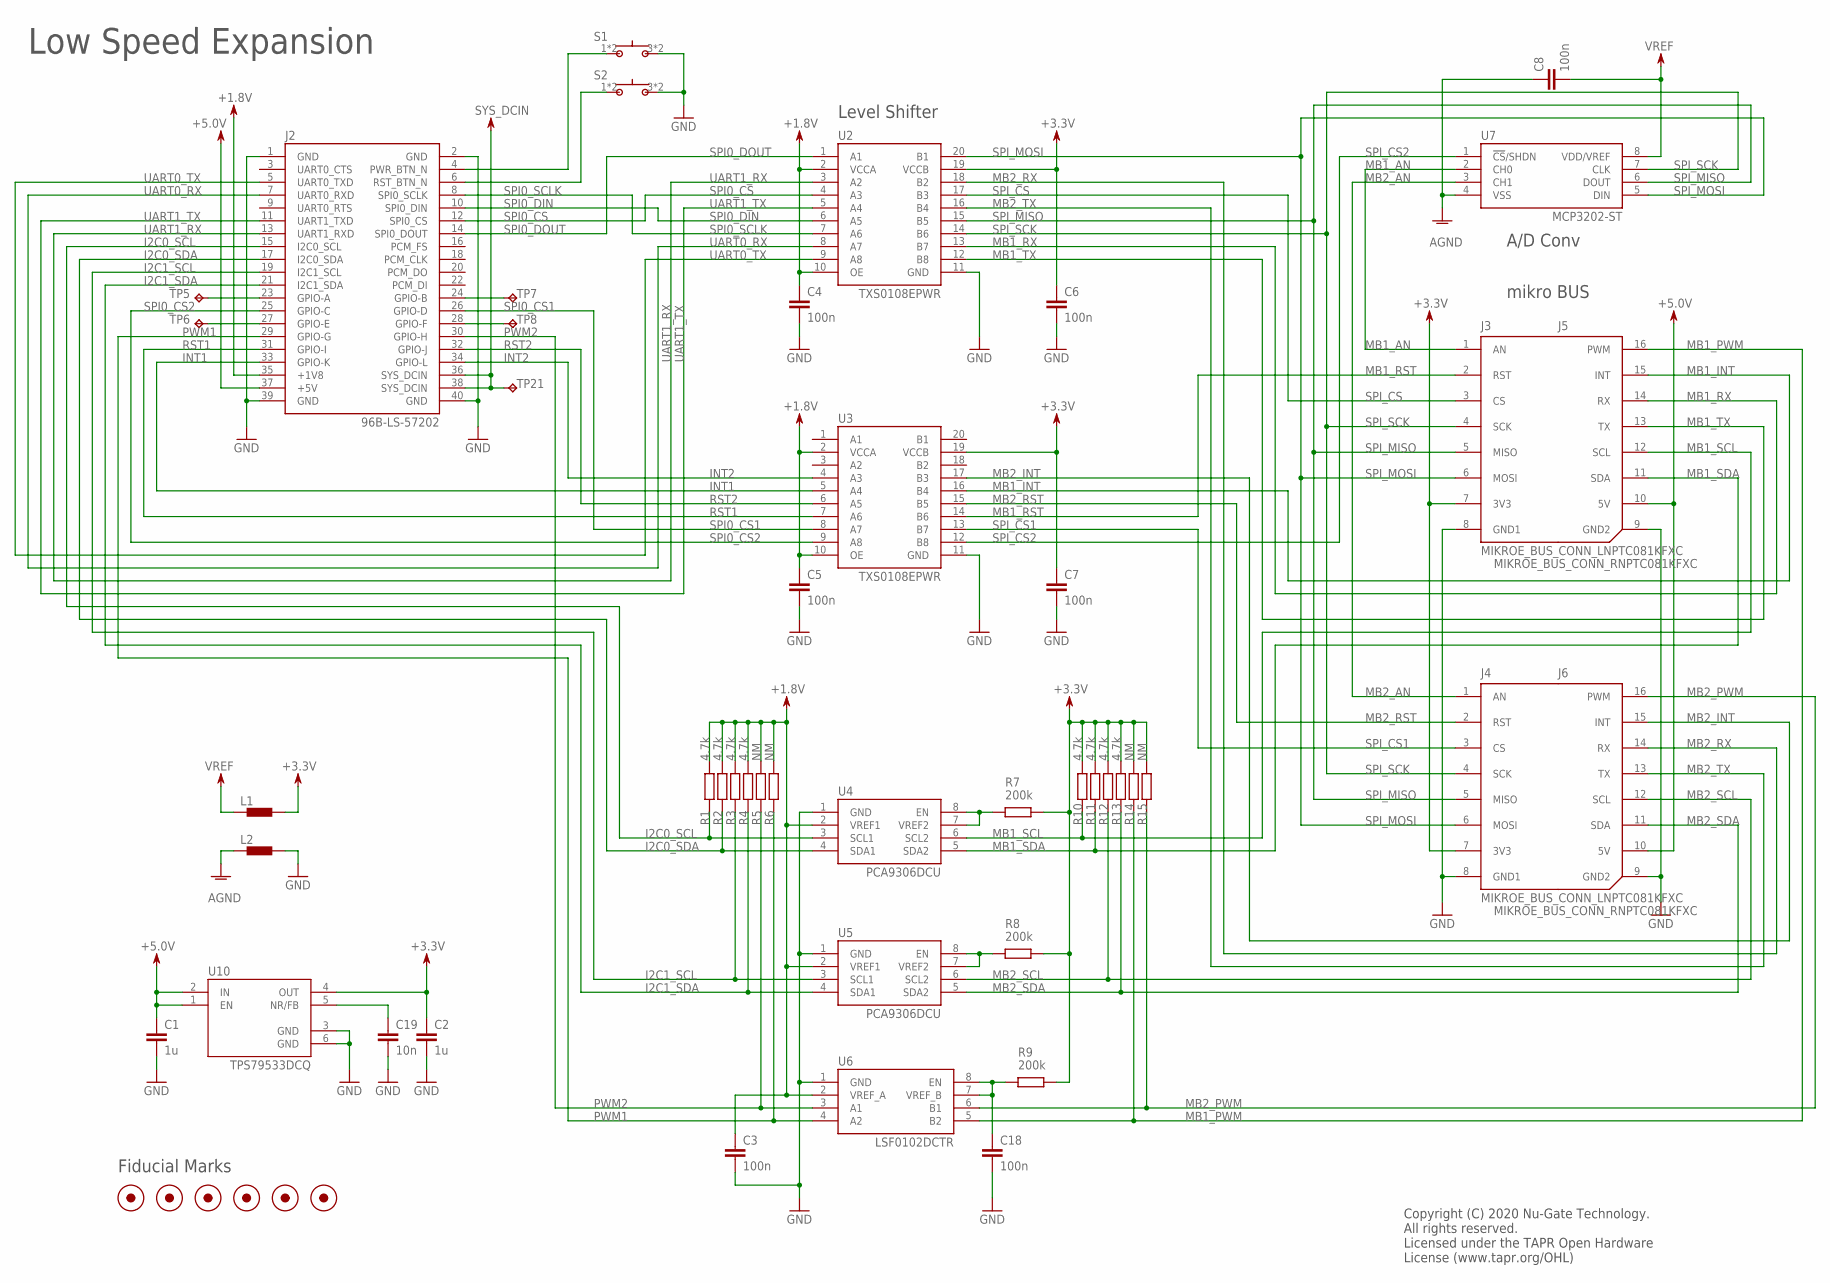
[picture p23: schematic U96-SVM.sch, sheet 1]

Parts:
C1, C2: 1u; C0402
C3, C4, C5, C6, C7, C8, C18: 100n; C0402
C19: 10n; C0402
FID1, FID2, FID3, FID4, FID5, FID6: FIDUCIAL; FIDUCIAL_1MM
J2: 96B-LS-57202; 57202-G52-20LF
J3, J4: MIKROE_BUS_CONN_LNPTC081KFXC; MIKROBUS_HOST_CONN_L2
J5, J6: MIKROE_BUS_CONN_RNPTC081KFXC; MIKROBUS_HOST_CONN_R2
L1, L2: BLM15AX; 0402
R1, R2, R3, R4, R10, R11, R12, R13: 4.7k; R0402
R5, R6, R14, R15: NM; R0402
R7, R8, R9: 200k; R0402
S1, S2: 430181038816
TP5, TP6, TP7, TP8, TP21: TPB1,27; B1,27
U2, U3: TXS0108EPWR; TI-PW20
U4, U5: PCA9306DCU; TI-DCU8
U6: LSF0102DCTR; TI-DCT8
U7: MCP3202-ST; MC-ST8
U10: TPS79533DCQ; TI-SOT223

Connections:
+1.8V: C3.1, C4.1, C5.1, J2.35 (+1V8), R1.2, R2.2, R3.2, R4.2, R5.2, R6.2, U2.2 (VCCA), U2.10 (OE), U3.2 (VCCA), U3.10 (OE), U4.2 (VREF1), U5.2 (VREF1), U6.2 (VREF_A); also elsewhere on the board
+3.3V: C2.1, C6.1, C7.1, J3.7 (3V3), J4.7 (3V3), L1.2, R7.2, R8.2, R9.2, R10.2, R11.2, R12.2, R13.2, R14.2, R15.2, U2.19 (VCCB), U3.19 (VCCB), U10.4 (OUT); also elsewhere on the board
+5.0V: C1.1, J2.37 (+5V), J5.10 (5V), J6.10 (5V), U10.1 (EN), U10.2 (IN); also elsewhere on the board
AGND: C8.1, L2.1, U7.4 (VSS)
GND: C1.2, C2.2, C3.2, C4.2, C5.2, C6.2, C7.2, C18.2, C19.2, J2.1 (GND), J2.2 (GND), J2.39 (GND), J2.40 (GND), J3.8 (GND1), J4.8 (GND1), J5.9 (GND2), J6.9 (GND2), L2.2, S1.3, S1.4, S2.3, S2.4, U2.11 (GND), U3.11 (GND), U4.1 (GND), U5.1 (GND), U6.1 (GND), U10.3 (GND), U10.6 (GND); also elsewhere on the board
I2C0_SCL: J2.15 (I2C0_SCL), R1.1, U4.3 (SCL1)
I2C0_SDA: J2.17 (I2C0_SDA), R2.1, U4.4 (SDA1)
I2C1_SCL: J2.19 (I2C1_SCL), R3.1, U5.3 (SCL1)
I2C1_SDA: J2.21 (I2C1_SDA), R4.1, U5.4 (SDA1)
INT1: J2.33 (GPIO-K), U3.5 (A4)
INT2: J2.34 (GPIO-L), U3.4 (A3)
MB1_AN: J3.1 (AN), U7.2 (CH0)
MB1_INT: J5.15 (INT), U3.16 (B4)
MB1_PWM: J5.16 (PWM), R14.1, U6.5 (B2)
MB1_RST: J3.2 (RST), U3.14 (B6)
MB1_RX: J5.14 (RX), U2.13 (B7)
MB1_SCL: J5.12 (SCL), R10.1, U4.6 (SCL2)
MB1_SDA: J5.11 (SDA), R11.1, U4.5 (SDA2)
MB1_TX: J5.13 (TX), U2.12 (B8)
MB2_AN: J4.1 (AN), U7.3 (CH1)
MB2_INT: J6.15 (INT), U3.17 (B3)
MB2_PWM: J6.16 (PWM), R15.1, U6.6 (B1)
MB2_RST: J4.2 (RST), U3.15 (B5)
MB2_RX: J6.14 (RX), U2.18 (B2)
MB2_SCL: J6.12 (SCL), R12.1, U5.6 (SCL2)
MB2_SDA: J6.11 (SDA), R13.1, U5.5 (SDA2)
MB2_TX: J6.13 (TX), U2.16 (B4)
unnamed: R7.1, U4.7 (VREF2), U4.8 (EN)
unnamed: C18.1, R9.1, U6.7 (VREF_B), U6.8 (EN)
unnamed: R8.1, U5.7 (VREF2), U5.8 (EN)
unnamed: C19.1, U10.5 (NR/FB)
unnamed: J2.23 (GPIO-A), TP5.TP
unnamed: J2.4 (PWR_BTN_N), S1.1, S1.2
unnamed: J2.6 (RST_BTN_N), S2.1, S2.2
unnamed: J2.27 (GPIO-E), TP6.TP
unnamed: J2.24 (GPIO-B), TP7.TP
unnamed: J2.28 (GPIO-F), TP8.TP
PWM1: J2.29 (GPIO-G), R6.1, U6.4 (A2)
PWM2: J2.30 (GPIO-H), R5.1, U6.3 (A1)
RST1: J2.31 (GPIO-I), U3.7 (A6)
RST2: J2.32 (GPIO-J), U3.6 (A5)
SPI0_CS: J2.12 (SPI0_CS), U2.4 (A3)
SPI0_CS1: J2.26 (GPIO-D), U3.8 (A7)
SPI0_CS2: J2.25 (GPIO-C), U3.9 (A8)
SPI0_DIN: J2.10 (SPI0_DIN), U2.6 (A5)
SPI0_DOUT: J2.14 (SPI0_DOUT), U2.1 (A1)
SPI0_SCLK: J2.8 (SPI0_SCLK), U2.7 (A6)
SPI_CS: J3.3 (CS), U2.17 (B3)
SPI_CS1: J4.3 (CS), U3.13 (B7)
SPI_CS2: U3.12 (B8), U7.1 (!CS!/SHDN)
SPI_MISO: J3.5 (MISO), J4.5 (MISO), U2.15 (B5), U7.6 (DOUT)
SPI_MOSI: J3.6 (MOSI), J4.6 (MOSI), U2.20 (B1), U7.5 (DIN)
SPI_SCK: J3.4 (SCK), J4.4 (SCK), U2.14 (B6), U7.7 (CLK)
SYS_DCIN: J2.36 (SYS_DCIN), J2.38 (SYS_DCIN), TP21.TP
UART0_RX: J2.7 (UART0_RXD), U2.8 (A7)
UART0_TX: J2.5 (UART0_TXD), U2.9 (A8)
UART1_RX: J2.13 (UART1_RXD), U2.3 (A2)
UART1_TX: J2.11 (UART1_TXD), U2.5 (A4)
VREF: C8.2, L1.1, U7.8 (VDD/VREF)

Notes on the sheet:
Fiducial Marks
Low Speed Expansion
Level Shifter
mikro BUS
A/D Conv
Copyright (C) 2020 Nu-Gate Technology. All rights reserved. Licensed under the TAPR Open Hardware License (www.tapr.org/OHL)

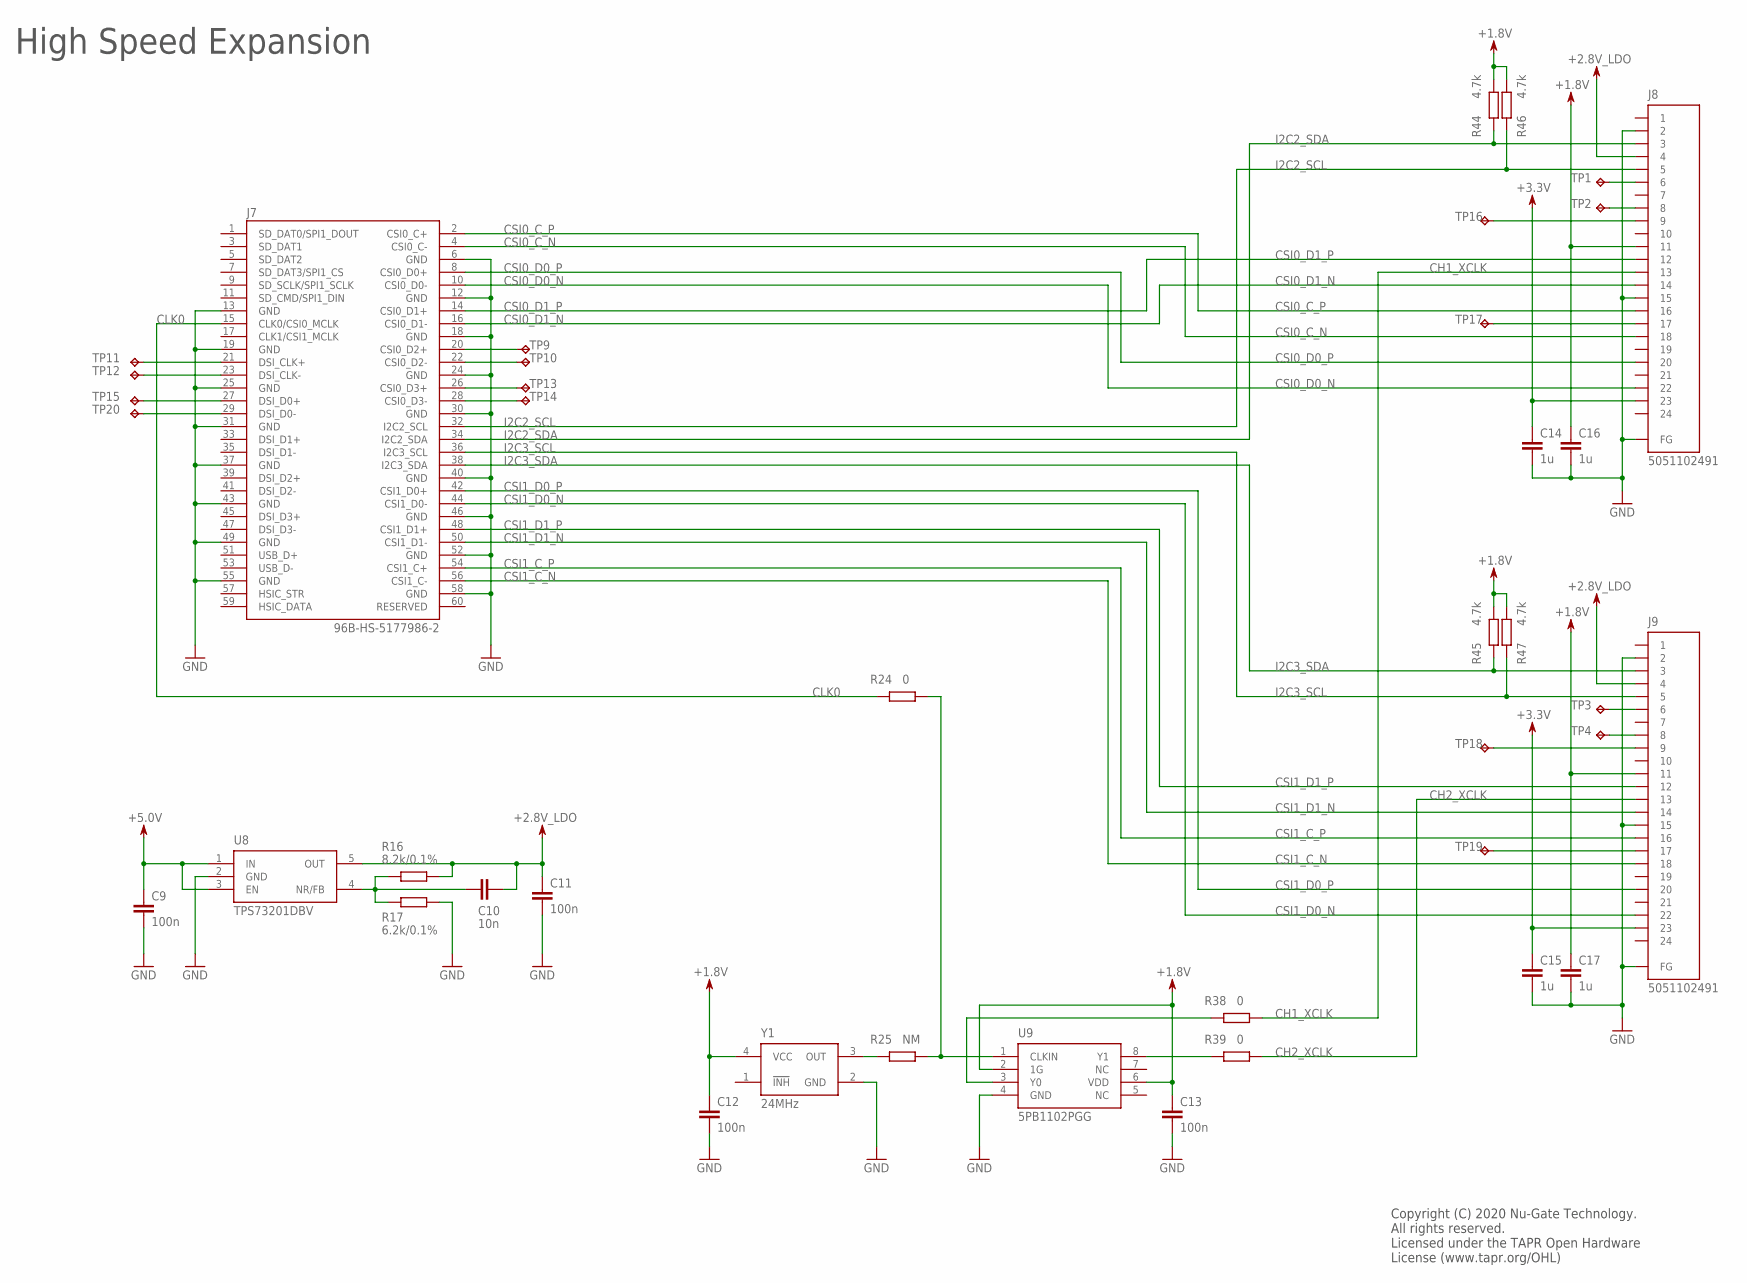
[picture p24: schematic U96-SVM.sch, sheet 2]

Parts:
C9, C11, C12, C13: 100n; C0402
C10: 10n; C0402
C14, C15, C16, C17: 1u; C0402
J7: 96B-HS-5177986-2; 5177986-2
J8, J9: 5051102491; MO-5051102491
R16: 8.2k/0.1%; R0402
R17: 6.2k/0.1%; R0402
R24, R38, R39: 0; R0402
R25: NM; R0402
R44, R45, R46, R47: 4.7k; R0402
TP1, TP2, TP3, TP4, TP9, TP10, TP11, TP12, TP13, TP14, TP15, TP16, TP17, TP18, TP19, TP20: TPB1,27; B1,27
U8: TPS73201DBV; TI-SOT23
U9: 5PB1102PGG; ID-TSSOP8
Y1: 24MHz; KC2520Z

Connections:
+1.8V: C12.1, C13.1, C16.1, C17.1, J8.11, J9.11, R44.2, R45.2, R46.2, R47.2, U9.2 (1G), U9.6 (VDD), Y1.4 (VCC); also elsewhere on the board
+2.8V_LDO: C10.2, C11.1, J8.4, J9.4, R16.2, U8.5 (OUT)
+3.3V: C14.1, C15.1, J8.23, J9.23; also elsewhere on the board
+5.0V: C9.1, U8.1 (IN), U8.3 (EN); also elsewhere on the board
CH1_XCLK: J8.13, R38.2
CH2_XCLK: J9.13, R39.2
CLK0: J7.15 (CLK0/CSI0_MCLK), R24.1
CSI0_C_N: J7.4 (CSI0_C-), J8.18
CSI0_C_P: J7.2 (CSI0_C+), J8.16
CSI0_D0_N: J7.10 (CSI0_D0-), J8.22
CSI0_D0_P: J7.8 (CSI0_D0+), J8.20
CSI0_D1_N: J7.16 (CSI0_D1-), J8.14
CSI0_D1_P: J7.14 (CSI0_D1+), J8.12
CSI1_C_N: J7.56 (CSI1_C-), J9.18
CSI1_C_P: J7.54 (CSI1_C+), J9.16
CSI1_D0_N: J7.44 (CSI1_D0-), J9.22
CSI1_D0_P: J7.42 (CSI1_D0+), J9.20
CSI1_D1_N: J7.50 (CSI1_D1-), J9.14
CSI1_D1_P: J7.48 (CSI1_D1+), J9.12
GND: C9.2, C11.2, C12.2, C13.2, C14.2, C15.2, C16.2, C17.2, J7.6 (GND), J7.12 (GND), J7.13 (GND), J7.18 (GND), J7.19 (GND), J7.24 (GND), J7.25 (GND), J7.30 (GND), J7.31 (GND), J7.37 (GND), J7.40 (GND), J7.43 (GND), J7.46 (GND), J7.49 (GND), J7.52 (GND), J7.55 (GND), J7.58 (GND), J8.2, J8.15, J8.FG@1 (FG), J8.FG@2 (FG), J9.2, J9.15, J9.FG@1 (FG), J9.FG@2 (FG), R17.2, U8.2 (GND), U9.4 (GND), Y1.2 (GND); also elsewhere on the board
I2C2_SCL: J7.32 (I2C2_SCL), J8.5, R46.1
I2C2_SDA: J7.34 (I2C2_SDA), J8.3, R44.1
I2C3_SCL: J7.36 (I2C3_SCL), J9.5, R47.1
I2C3_SDA: J7.38 (I2C3_SDA), J9.3, R45.1
unnamed: J8.6, TP1.TP
unnamed: J8.8, TP2.TP
unnamed: J9.6, TP3.TP
unnamed: J9.8, TP4.TP
unnamed: C10.1, R16.1, R17.1, U8.4 (NR/FB)
unnamed: J7.21 (DSI_CLK+), TP11.TP
unnamed: J7.23 (DSI_CLK-), TP12.TP
unnamed: J7.27 (DSI_D0+), TP15.TP
unnamed: J7.29 (DSI_D0-), TP20.TP
unnamed: J7.20 (CSI0_D2+), TP9.TP
unnamed: J7.22 (CSI0_D2-), TP10.TP
unnamed: J7.26 (CSI0_D3+), TP13.TP
unnamed: J7.28 (CSI0_D3-), TP14.TP
unnamed: R25.1, Y1.3 (OUT)
unnamed: R24.2, R25.2, U9.1 (CLKIN)
unnamed: R39.1, U9.8 (Y1)
unnamed: R38.1, U9.3 (Y0)
unnamed: J8.9, TP16.TP
unnamed: J8.17, TP17.TP
unnamed: J9.9, TP18.TP
unnamed: J9.17, TP19.TP

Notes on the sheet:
High Speed Expansion
Copyright (C) 2020 Nu-Gate Technology. All rights reserved. Licensed under the TAPR Open Hardware License (www.tapr.org/OHL)

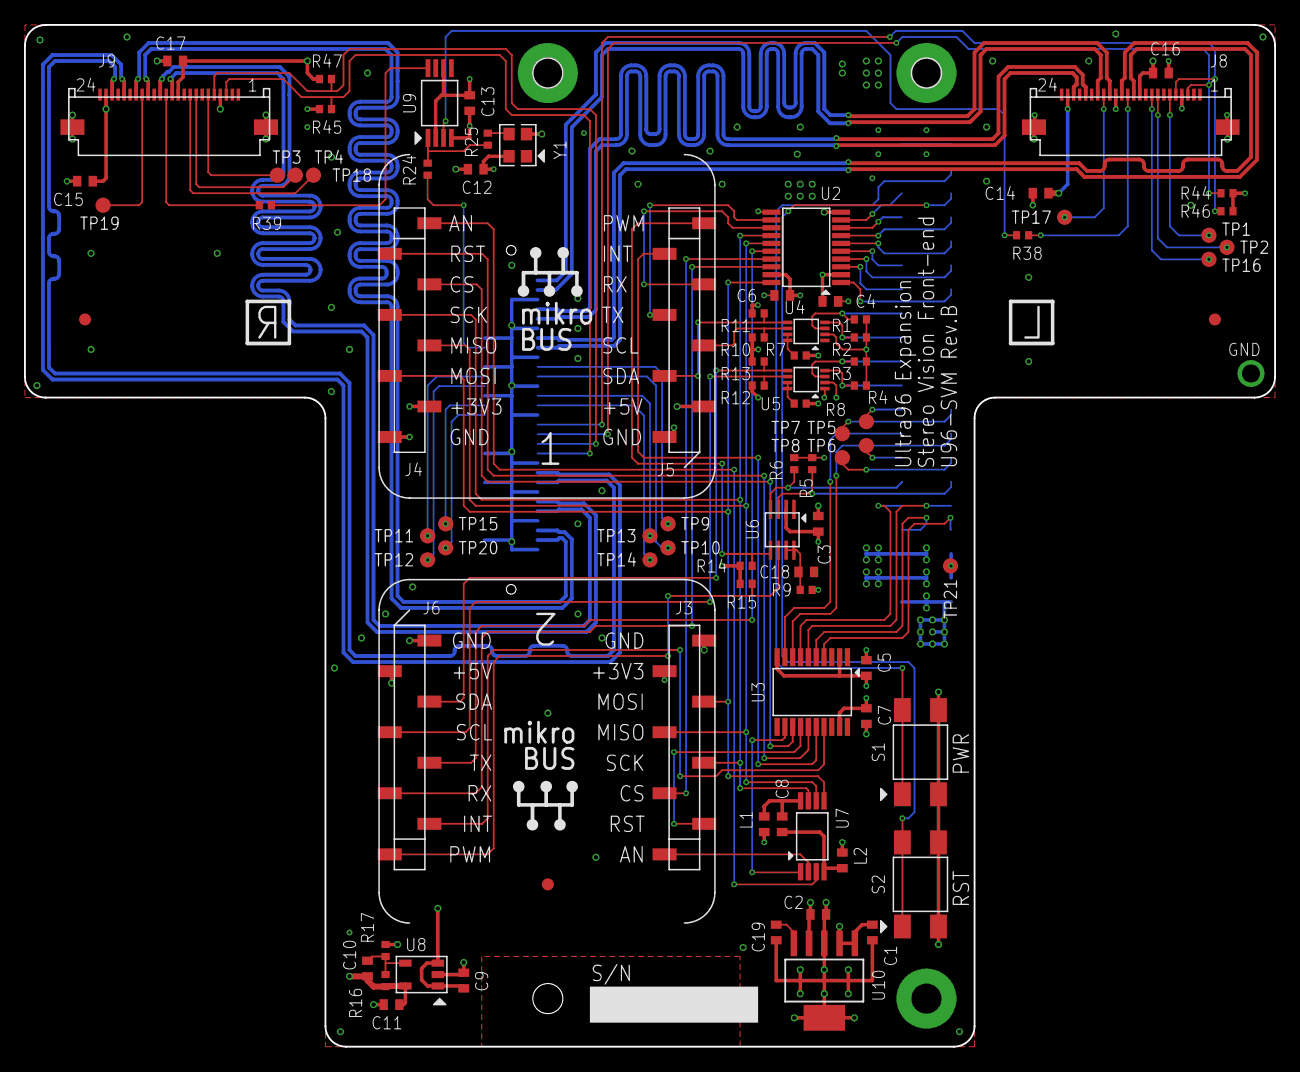
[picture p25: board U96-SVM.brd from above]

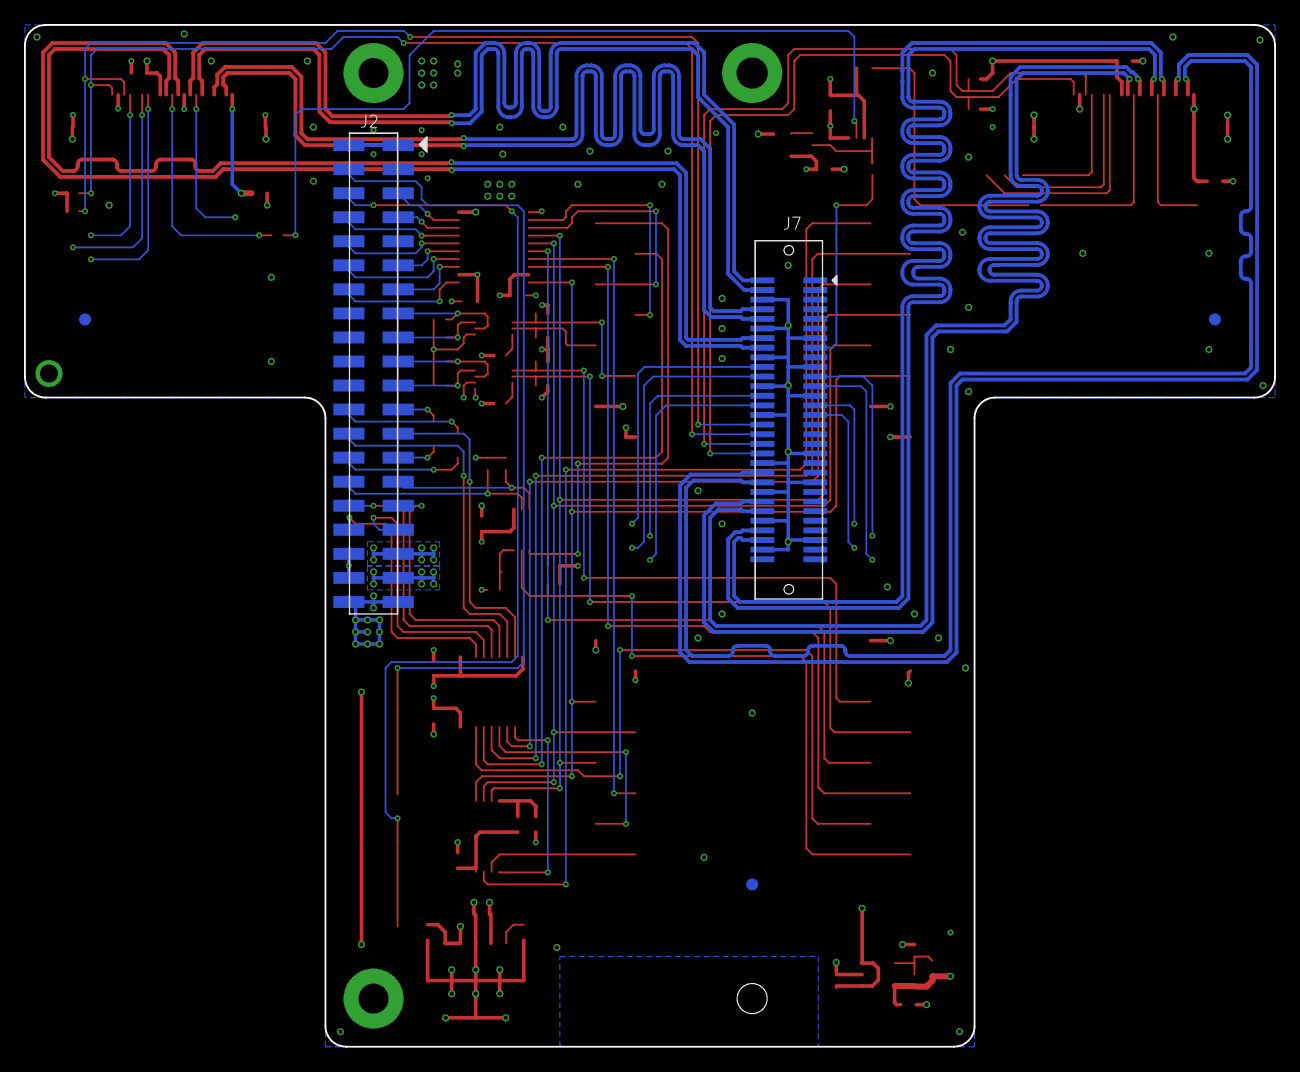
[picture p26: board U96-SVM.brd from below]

Board: 4 copper layers, 104.0 x 85.0 mm, 100 parts (5 on the bottom side), 100 nets.

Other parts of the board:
U$1: 96BOARDS_FORM_FACTOR
U$2, U$3: FD5640-500W
U$4, U$7: MIKROBUS_LOGO1
U$5, U$6: MIKROBUS_LOGO2

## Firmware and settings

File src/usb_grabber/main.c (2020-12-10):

//=============================================================================
// Copyright (C) 2020 Nu-Gate Technology. All rights reserved.
// SPDX-License-Identifier: MIT
//=============================================================================
//=============================================================================
//!
//! @file main.c
//!
//! Main C source file for usb_grabber project.
//!
//! <pre>
//! MODIFICATION HISTORY:
//!
//! Ver   Who  Date       Changes
//! ----- ---- ---------- -----------------------------------------------------
//! 1.0   sd   2020.12.07 First release
//! </pre>
//=============================================================================
#include "main.h"

extern volatile struct FPGA_REG *fpga;
extern struct XUSB_TX_INFO tx_info;
extern struct Usb_DevData UsbInstance;

extern struct I2C_REG *i2c;


//=============================================================================
//! PL Interrupt Handler
//-----------------------------------------------------------------------------
//! @param *CallBackRef	Pointer to UVC_APP_DATA
//-----------------------------------------------------------------------------
//! @brief Interrupt handler for PL interrupt. This handler will be called
//! every time a frame of image data is DMA-transferred.
//=============================================================================
void PL_IntrHandler(void *CallBackRef)
{
	if ((fpga->com.InterruptStatus & FPGA_INTR_GRB_L) == FPGA_INTR_GRB_L) {
		// clear interrupt
		fpga->com.InterruptStatus = FPGA_INTR_GRB_L;

		// application specific data structure
		struct UVC_APP_DATA *app_data = Uvc_GetAppData(CallBackRef);

		// read active bank
		app_data->bank = Fpga_ReadActiveBank();
		app_data->img_received += 1;
	}
}

//=============================================================================
//! Setup Interrupt System
//-----------------------------------------------------------------------------
//! @param IntcDeviceID	Device ID of SCU GIC
//! @param *IntcPtr		Pointer to the instance of the interrupt controller
//-----------------------------------------------------------------------------
//! @return XST_SUCCESS when succeed else XST_FAILURE
//-----------------------------------------------------------------------------
//! @brief This function sets up the interrupt system for this application.
//! There are two interrupt sources in this design, USB and PL.
//=============================================================================
s32 SetupInterruptSystem (
	u16 IntcDeviceID,
	void *IntcPtr
){
	s32 Status;

	//-----------------------------------------------------------
	// Initialize GIC
	//-----------------------------------------------------------
	XScuGic_Config *IntcConfig;

	XScuGic *IntcInstancePtr = (XScuGic*)IntcPtr;

	// Initialize the interrupt controller driver
	IntcConfig = XScuGic_LookupConfig(IntcDeviceID);
	if (NULL == IntcConfig) {
		return XST_FAILURE;
	}

	Status = XScuGic_CfgInitialize(
		IntcInstancePtr,
		IntcConfig,
		IntcConfig->CpuBaseAddress
	);
	if (Status != XST_SUCCESS) {
		return XST_FAILURE;
	}

	//-----------------------------------------------------------
	// Setup Individual Interrupt Source
	//-----------------------------------------------------------
	// USB
	Status = Xusb_SetupInterrupt (IntcPtr);
	if (Status != XST_SUCCESS) {
		return XST_FAILURE;
	}

	// PL
	Status = PL_SetupInterrupt (IntcConfig, IntcPtr, &UsbInstance);
	if (Status != XST_SUCCESS) {
		return XST_FAILURE;
	}

	//-----------------------------------------------------------
	// Enable Interrupt for ARM
	//-----------------------------------------------------------
	// Register interrupt handlers to ARM core.
	Xil_ExceptionRegisterHandler(
		XIL_EXCEPTION_ID_INT,
		(Xil_ExceptionHandler)XScuGic_InterruptHandler,
		IntcInstancePtr
	);

	// Enable interrupts in ARM
	Xil_ExceptionEnable();

	return XST_SUCCESS;
}

//=============================================================================
//! PL Setup Interrupt
//-----------------------------------------------------------------------------
//! @param *IntcConfig	Pointer to the configuration information of the
//! XScuGic driver.
//! @param *IntcPtr		Pointer to the instance of the interrupt controller
//! @param *UsbInstance Pointer to the Usb_DevData
//-----------------------------------------------------------------------------
//! @return XST_SUCCESS when succeed else XST_FAILURE
//-----------------------------------------------------------------------------
//! @brief This function sets up the PL interrupt.
//=============================================================================
s32 PL_SetupInterrupt (
	XScuGic_Config *IntcConfig,
	void *IntcPtr,
	struct Usb_DevData *UsbInstance
) {
	s32 Status;

	// Connect to the interrupt controller
	Status = XScuGic_Connect(
		(XScuGic*)IntcPtr,
		XPS_FPGA0_INT_ID,
		(Xil_ExceptionHandler)PL_IntrHandler,
		UsbInstance
	);
	if (Status != XST_SUCCESS) {
		return XST_FAILURE;
	}

	// set sensitivity type and priority
	XScuGic_SetPriTrigTypeByDistAddr(
		IntcConfig->DistBaseAddress,
		XPS_FPGA0_INT_ID,		// Int_Id
		32,		// Priority
		//2		// Trigger, edge-triggered
		0		// Trigger, level-sensitive
	);

	// Enable the interrupt for the USB
	XScuGic_Enable((XScuGic*)IntcPtr, XPS_FPGA0_INT_ID);

	return XST_SUCCESS;
}

//=============================================================================
//! Assertion Callback Function
//-----------------------------------------------------------------------------
//! @param *File	File name of the source code where the assertion was
//! triggered.
//! @param Line		Line number of the source code where the assertion was
//! triggered.
//-----------------------------------------------------------------------------
//! @brief This function will be called when assertion is triggered.
//=============================================================================
void AssertCallBack (const char8 *File, s32 Line) {
	xil_printf("[Assert] %s, %d\r\n", File, Line);
}

//=============================================================================
//! Main Function
//-----------------------------------------------------------------------------
//! @brief Main function of this application.
//=============================================================================
int main (void)
{
	//Xil_ICacheDisable();
	//Xil_DCacheDisable();

	Xil_AssertSetCallback((Xil_AssertCallback)AssertCallBack);

	xil_printf("\r\n\r\n");
	xil_printf("/*******************************************************/\r\n");
	xil_printf("/*                Hardware Test Program                */\r\n");
	xil_printf("/*                         for                         */\r\n");
	xil_printf("/*                       U96-SVM                       */\r\n");
	xil_printf("/*                by Nu-Gate Technology                */\r\n");
	xil_printf("/*******************************************************/\r\n");
	xil_printf("FPGA ver.%08lx\r\n", Fpga_ReadVersion());
	xil_printf("%s:%s\r\n", __DATE__, __TIME__);

	xil_printf("Start USB Frame Grabber\r\n");
	App_UsbGrabber();

	while(1){
		CommandProcess();
	}

	return 0;
}

//=============================================================================
//! Prompt
//-----------------------------------------------------------------------------
//! Shows prompt to screen.
//=============================================================================
void Prompt (void) {
	xil_printf(">");
	return;
}

//=============================================================================
//! Command Process
//-----------------------------------------------------------------------------
//! Main loop of command process. This function receive a new command and
//! execute it sequentially.
//=============================================================================
void CommandProcess (void)
{
	struct HWTP_CMD cmd;

	while(1){
		Prompt();
		CommandAnalyze(&cmd);
		CommandExecute(cmd);
	}

	return;
}

//=============================================================================
//! Command Receive
//-----------------------------------------------------------------------------
//! Receives a new command.
//=============================================================================
void CommandReceive (
	char* buf, int len
){
	int n = 0;
	while(1){
		buf[n] = uart_getc();
		n++;

		if ((buf[n-1] == 0x0d) || (n == len)) {
			xil_printf("\r\n");
			buf[n-1] = 0x00;
			break;
		} else if (buf[n-1] == 0x08) { // BS
			if (n >= 2) n -= 2;
		}
	}

	return;
}

//=============================================================================
//! Command Analyze
//-----------------------------------------------------------------------------
//! Decompose a received command into a set of parameters.
//=============================================================================
void CommandAnalyze (
	struct HWTP_CMD *cmd
) {
	char buf[128];

	// Receive 1 command line
	CommandReceive(buf, sizeof(buf));
	int len = strlen(buf);

	// Decompose into set of parameters
	int n_parm = 0;
	int n = 0;
	for (int i = 0; i <= len; i++) {
		if (buf[i] == 0x20) {
			if (n != 0) {
				cmd->parm[n_parm][n] = 0x00;
				n = 0;
				n_parm++;
			}
			else {
				// skip successive space
			}
		} else {
			if (n < sizeof(cmd->parm[n_parm])) {
				cmd->parm[n_parm][n] = tolower(buf[i]);
				n++;
			}
		}
	}

	// number of parameters - 1
	cmd->num = n_parm;

	return;
}

//=============================================================================
//! Command Execute
//-----------------------------------------------------------------------------
//! Executes a receive command.
//=============================================================================
void CommandExecute (
	struct HWTP_CMD cmd
) {
	if (strcmp(cmd.parm[0], "ol") == 0) {
		// Output LONG
		unsigned long addr, data;
		hex_to_num(cmd.parm[1], &addr);
		hex_to_num(cmd.parm[2], &data);
		volatile unsigned int* ptr = (volatile unsigned int*)addr;
		*ptr = data;
	} else if (strcmp(cmd.parm[0], "ow") == 0) {
		// Output WORD
		unsigned long addr, data;;
		hex_to_num(cmd.parm[1], &addr);
		hex_to_num(cmd.parm[2], &data);
		volatile unsigned short* ptr = (volatile unsigned short*)addr;
		*ptr = (unsigned short)(data & 0xFFFF);
	} else if (strcmp(cmd.parm[0], "oc") == 0) {
		// Output CHAR
		unsigned long addr, data;;
		hex_to_num(cmd.parm[1], &addr);
		hex_to_num(cmd.parm[2], &data);
		volatile unsigned char* ptr = (volatile unsigned char*)addr;
		*ptr = (unsigned char)(data & 0xFF);
	} else if (strcmp(cmd.parm[0], "il") == 0) {
		// Input LONG
		unsigned long addr;
		hex_to_num(cmd.parm[1], &addr);
		volatile unsigned int* ptr = (volatile unsigned int*)addr;
		xil_printf("%08lX\r\n", *ptr);
	} else if (strcmp(cmd.parm[0], "iw") == 0) {
		// Input WORD
		unsigned long addr;
		hex_to_num(cmd.parm[1], &addr);
		volatile unsigned short* ptr = (volatile unsigned short*)addr;
		xil_printf("%04X\r\n", *ptr);
	} else if (strcmp(cmd.parm[0], "ic") == 0) {
		// Input CHAR
		unsigned long addr;
		hex_to_num(cmd.parm[1], &addr);
		volatile unsigned char* ptr = (volatile unsigned char*)addr;
		xil_printf("%02X\r\n", *ptr);
	} else if (strcmp(cmd.parm[0], "dl") == 0) {
		// Dump LONG
		unsigned long addr;
		hex_to_num(cmd.parm[1], &addr);
		volatile unsigned int* ptr = (volatile unsigned int*)addr;
		for (int i = 0; i < 16; i++) {
			if (i % 4 == 0) xil_printf("%08lX: ", ptr);
			xil_printf("%08lX ", *ptr++);
			if (i % 4 == 3) xil_printf("\r\n");
		}
	} else if (strcmp(cmd.parm[0], "dw") == 0) {
		// Dump WORD
		unsigned long addr;
		hex_to_num(cmd.parm[1], &addr);
		volatile unsigned short* ptr = (volatile unsigned short*)addr;
		for (int i = 0; i < 32; i++) {
			if (i % 8 == 0) xil_printf("%08lX: ", ptr);
			xil_printf("%04X ", *ptr++);
			if (i % 8 == 7) xil_printf("\r\n");
		}
	} else if (strcmp(cmd.parm[0], "dc") == 0) {
		// Dump CHAR
		unsigned long addr;
		hex_to_num(cmd.parm[1], &addr);
		volatile unsigned char* ptr = (volatile unsigned char*)addr;
		for (int i = 0; i < 64; i++) {
			if (i % 16 == 0) xil_printf("%08lX: ", ptr);
			xil_printf("%02X ", *ptr++);
			if (i % 16 == 15) xil_printf("\r\n");
		}
	} else if (strcmp(cmd.parm[0], "r") == 0) {
		unsigned long addr;
		unsigned char data;
		if(cmd.num != 1) {
			xil_printf("Invalid parameters\r\n");
		} else {
			hex_to_num(cmd.parm[1], &addr);
			Ov5640_I2cRead((unsigned int)addr, &data);
			xil_printf("%02X\r\n", data);
		}
	} else if (strcmp(cmd.parm[0], "w") == 0) {
		unsigned long addr, data;
		if(cmd.num != 2) {
			xil_printf("Invalid parameters\r\n");
		} else {
			hex_to_num(cmd.parm[1], &addr);
			hex_to_num(cmd.parm[2], &data);
			Ov5640_I2cWrite((unsigned int)addr, (unsigned char)data);
		}
	} else if (strcmp(cmd.parm[0], "t1") == 0) {
		I2c_Init();
	} else if (strcmp(cmd.parm[0], "t2") == 0) {
		I2c_ShowStatus();
	} else if (strcmp(cmd.parm[0], "t3") == 0) {
		I2c_SetCh(I2C_SEL_CH2 | I2C_SEL_CH3);
	} else if (strcmp(cmd.parm[0], "t4") == 0) {
		unsigned char ch;
		I2c_ReadCh(&ch);
		xil_printf("ch %d\r\n", ch);
	} else if (strcmp(cmd.parm[0], "t5") == 0) {
		Ov5640_I2cWrite(0x3000, 0xAA);
	} else if (strcmp(cmd.parm[0], "t6") == 0) {
		unsigned char val;
		Ov5640_I2cRead(0x3000, &val);
		xil_printf("val %02X\r\n", val);
	} else if (strcmp(cmd.parm[0], "t7") == 0) {
	} else if (strcmp(cmd.parm[0], "t8") == 0) {
	} else if (strcmp(cmd.parm[0], "t9") == 0) {
	} else if (strcmp(cmd.parm[0], "t10") == 0) {
		unsigned int *addr = (unsigned int *)0x40000000;
		for (int i = 0; i < 0x10000000; i+=4) {
			*addr = 0;
			addr++;
		}
	} else if (strcmp(cmd.parm[0], "t11") == 0) {
		unsigned int *addr = (unsigned int *)0x40000000;
		Xil_DCacheInvalidateRange((UINTPTR)addr, 0x1000);
	} else if (strcmp(cmd.parm[0], "t12") == 0) {
		fpga->arb.Control   = 0x00000001;
		fpga->grb_l.Control   = 0x00000001;
		fpga->grb_l.Address_A = 0x40000000;
		fpga->grb_l.Trigger   = 0x00000001;
	} else if (strcmp(cmd.parm[0], "t13") == 0) {
		// dump image buffer
		unsigned int *addr;
		addr = (unsigned int *)0x40000000;

		for (int h = 0; h < 480; h++) {
			for (int w = 0; w < 640; w++) {
				xil_printf("%08X,", *addr);
				//xil_printf("%03X,", *addr);
				addr++;
			}
		}
	} else if (strcmp(cmd.parm[0], "t14") == 0) {
		// read WHO_AM_I register from LSM9DS1 Accel & Gyro
		I2c_Init();
		I2c_SetCh(I2C_SEL_CH0);

		unsigned char reg_addr = 0x0F;
		I2c_Write(0x6A, &reg_addr, 1);

		unsigned char reg_value;
		I2c_Read(0x6A, &reg_value, 1);

		xil_printf("%X\r\n", reg_value);
	} else if (strcmp(cmd.parm[0], "t15") == 0) {
		unsigned char reg_value[2];
		unsigned long tmpl;

		// Register Address
		hex_to_num(cmd.parm[1], &tmpl);
		reg_value[0] = (unsigned char)tmpl;

		// Register Value
		hex_to_num(cmd.parm[2], &tmpl);
		reg_value[1] = (unsigned char)tmpl;

		Lsm9ds1_XlgWrite(reg_value[0], reg_value[1]);
	} else if (strcmp(cmd.parm[0], "t16") == 0) {
		unsigned char reg_addr, reg_value;
		unsigned long tmpl;

		// Register Address
		hex_to_num(cmd.parm[1], &tmpl);
		reg_addr = (unsigned char)tmpl;

		Lsm9ds1_XlgRead(reg_addr, &reg_value);
		xil_printf("read %x\r\n", reg_value);
	} else if (strcmp(cmd.parm[0], "t17") == 0) {
		unsigned char reg_value[2];
		unsigned long tmpl;

		// Register Address
		hex_to_num(cmd.parm[1], &tmpl);
		reg_value[0] = (unsigned char)tmpl;

		// Register Value
		hex_to_num(cmd.parm[2], &tmpl);
		reg_value[1] = (unsigned char)tmpl;

		Lsm9ds1_MagWrite(reg_value[0], reg_value[1]);
	} else if (strcmp(cmd.parm[0], "t18") == 0) {
		unsigned char reg_addr, reg_value;
		unsigned long tmpl;

		// Register Address
		hex_to_num(cmd.parm[1], &tmpl);
		reg_addr = (unsigned char)tmpl;

		Lsm9ds1_MagRead(reg_addr, &reg_value);
		xil_printf("read %x\r\n", reg_value);
	} else if (strcmp(cmd.parm[0], "t19") == 0) {
		I2c_Init();
		//I2c_SetCh(I2C_SEL_CH0);
		I2c_SetCh(I2C_SEL_CH1);

		Lsm9ds1_MagWrite(MAG_ADDR_CTRL_REG3_M,		0x00);
		Lsm9ds1_MagWrite(MAG_ADDR_INT_CFG_M,		0xE1);
	} else if (strcmp(cmd.parm[0], "t20") == 0) {
		unsigned char reg_value;
		Lsm9ds1_MagRead(MAG_ADDR_STATUS_REG_M, &reg_value);
		xil_printf("MAG_ADDR_STATUS_REG_M: %08X\r\n", reg_value);
		Lsm9ds1_MagRead(MAG_ADDR_INT_SRC_M, &reg_value);
		xil_printf("MAG_ADDR_INT_SRC_M: %08X\r\n", reg_value);
	} else if (strcmp(cmd.parm[0], "t21") == 0) {
		unsigned char reg_value_h, reg_value_l;
		Lsm9ds1_MagRead(MAG_ADDR_OUT_X_L_M, &reg_value_l);
		Lsm9ds1_MagRead(MAG_ADDR_OUT_X_H_M, &reg_value_h);
		xil_printf("X:%02X%02X ", reg_value_h, reg_value_l);
		Lsm9ds1_MagRead(MAG_ADDR_OUT_Y_L_M, &reg_value_l);
		Lsm9ds1_MagRead(MAG_ADDR_OUT_Y_H_M, &reg_value_h);
		xil_printf("Y:%02X%02X ", reg_value_h, reg_value_l);
		Lsm9ds1_MagRead(MAG_ADDR_OUT_Z_L_M, &reg_value_l);
		Lsm9ds1_MagRead(MAG_ADDR_OUT_Z_H_M, &reg_value_h);
		xil_printf("Z:%02X%02X\r\n", reg_value_h, reg_value_l);
	} else if (strcmp(cmd.parm[0], "t23") == 0) {
		App_UsbGrabber();
	} else if (strcmp(cmd.parm[0], "t24") == 0) {
		App_9DofHwTest();
	} else if (strcmp(cmd.parm[0], "t25") == 0) {
	}

	return;
}

//=============================================================================
// Application Level Functions
//=============================================================================
//=============================================================================
//! USB Frame Grabber
//-----------------------------------------------------------------------------
//! @brief Main function of USB frame grabber application.
//=============================================================================
void App_UsbGrabber (void) {
	s32 Status;

	// Initialize FPGA
	Fpga_Init(IMG_BUF_A, IMG_BUF_B, IMG_BUF_C);

	// Initialize MIPI CSI Receiver
	Csi_Init(CSI_TWO_LANE);

	// Initialize OV5640
	int actual_scl = I2c_Init();
	xil_printf("SCL frequency is set to %d[Hz] (target %d)\r\n", actual_scl, I2C_TARGET_SCL);
	I2c_SetCh(I2C_SEL_CH2 | I2C_SEL_CH3);

	Ov5640_SoftwareReset (OV5640_RESET_ASSERT);
	usleep(1000);
	Ov5640_SoftwareReset (OV5640_RESET_RELEASE);

	Ov5640_Init(
		OV5640_TEST_NORMAL,
		OV5640_RESOLUTION_640_480,
		30.0
	);

	// Wait some time for PLLs to be stabilized
	usleep(1000000);

	// Check status
	Status = Csi_CheckStatus();
	Xil_AssertVoid(Status == XST_SUCCESS);

	// Initialize USB driver
	Status = Xusb_Init();
	Xil_AssertVoid(Status == XST_SUCCESS);

	// Setup interrupt
	Status = SetupInterruptSystem(
		INTC_DEVICE_ID,
		(void *)&InterruptController
	);
	Xil_AssertVoid(Status == XST_SUCCESS);

	// Start
	xil_printf("Start USB driver (Press ESC to leave)\r\n");
	Xusb_Main();
}

//=============================================================================
//! 9DOF Hardware Test
//-----------------------------------------------------------------------------
//! @brief Performs hardware test on MikroElektronika 9DOF click module
//! mounted on MB1/2 sites.
//=============================================================================
void App_9DofHwTest (void) {

	int found;
	unsigned char reg_value;
	unsigned int intr_sts, gpio;

	I2c_Init();

	found = 0;
	for (int ch = 0; ch < 2; ch++) {
		xil_printf("H/W test on MB site %d\r\n", ch + 1);

		// set channel
		if (ch == 0) {
			I2c_SetCh(I2C_SEL_CH0);
		} else {
			I2c_SetCh(I2C_SEL_CH1);
		}

		// read WHO_AM_I registers
		found = 1;
		intr_sts = Lsm9ds1_XlgRead (XLG_ADDR_WHO_AM_I, &reg_value);
		if (!I2c_IsTransferComplete(intr_sts) || (reg_value != XLG_WHO_AM_I)) {
			I2c_DiagnoseError(intr_sts);
			found = 0;
		} else {
			xil_printf("XLG WHO_AM_I: %02X\r\n", reg_value);
		}

		intr_sts = Lsm9ds1_MagRead (MAG_ADDR_WHO_AM_I_M, &reg_value);
		if (!I2c_IsTransferComplete(intr_sts) || (reg_value != MAG_WHO_AM_I)) {
			I2c_DiagnoseError(intr_sts);
			found = 0;
		} else {
			xil_printf("MAG WHO_AM_I: %02X\r\n", reg_value);
		}

		// interrupt signal test
		if (found == 1) {
			// enable interrupt
			Lsm9ds1_MagWrite(MAG_ADDR_CTRL_REG3_M,		0x00);
			Lsm9ds1_MagWrite(MAG_ADDR_INT_CFG_M,		0xE1);

			int count = 0;
			while(1) {
				if (ch == 0) {
					gpio = fpga->com.GPIO & 0x00000001;
				} else {
					gpio = (fpga->com.GPIO >> 1) & 0x00000001;
				}

				if (gpio == 0x00000001) {
					xil_printf("Interrupt from MB%d detected\r\n", ch + 1);
					Lsm9ds1_ReadMagValues();
					break;
				}

				if (count == 0x1000) {
					xil_printf("Interrupt from MB%d not detected\r\n", ch + 1);
					break;
				}

				count++;
			}
		}
		else {
			xil_printf("Device not found on MB%d\r\n", ch + 1);
		}
	}
}

//=============================================================================
// Helper Functions
//=============================================================================
//=============================================================================
//! Hexadecimal to Numerical
//-----------------------------------------------------------------------------
//! @param *hex		Pointer to an input hexadecimal number
//! @param *num		Converted data is stored here.
//-----------------------------------------------------------------------------
//! Converts hexadecimal number expressed in ASCII code string into numerical
//! value.
//=============================================================================
void hex_to_num (char* hex, unsigned long* num) {
	int id = 0;
	unsigned long val = 0;
	while(hex[id] != 0) {
		val *= 16;
		if ((0x30 <= hex[id]) && (hex[id] <= 0x39)) {
			// 0 - 9
			val += (hex[id] - 0x30);
		}
		else if ((0x41 <= hex[id]) && (hex[id] <= 0x46)) {
			// A - F
			val += (hex[id] - 0x37);
		}
		else if ((0x61 <= hex[id]) && (hex[id] <= 0x66)) {
			// a - f
			val += (hex[id] - 0x57);
		}
		id++;
	}

	*num = val;
}
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

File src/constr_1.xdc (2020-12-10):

set_property PACKAGE_PIN E8 [get_ports clk_out1_0]
set_property IOSTANDARD LVCMOS18 [get_ports clk_out1_0]
set_property PACKAGE_PIN C5 [get_ports {gpio_in_0[1]}]
set_property PACKAGE_PIN G6 [get_ports {gpio_in_0[0]}]
set_property IOSTANDARD LVCMOS18 [get_ports {gpio_in_0[1]}]
set_property IOSTANDARD LVCMOS18 [get_ports {gpio_in_0[0]}]
set_property PACKAGE_PIN B9 [get_ports {led_0[1]}]
set_property PACKAGE_PIN A9 [get_ports {led_0[0]}]
set_property IOSTANDARD LVCMOS18 [get_ports {led_0[1]}]
set_property IOSTANDARD LVCMOS18 [get_ports {led_0[0]}]
